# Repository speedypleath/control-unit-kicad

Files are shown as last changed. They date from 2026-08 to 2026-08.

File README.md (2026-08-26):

# Haptic Console — Control Unit (M6) KiCad Project

KiCad project for the Control Unit module of the Haptic Console v1.0. One schematic,
two PCBs: a compact manufactured board (SMD, routed, ready for fab) and a hand-wireable
perfboard build.

## Schematic

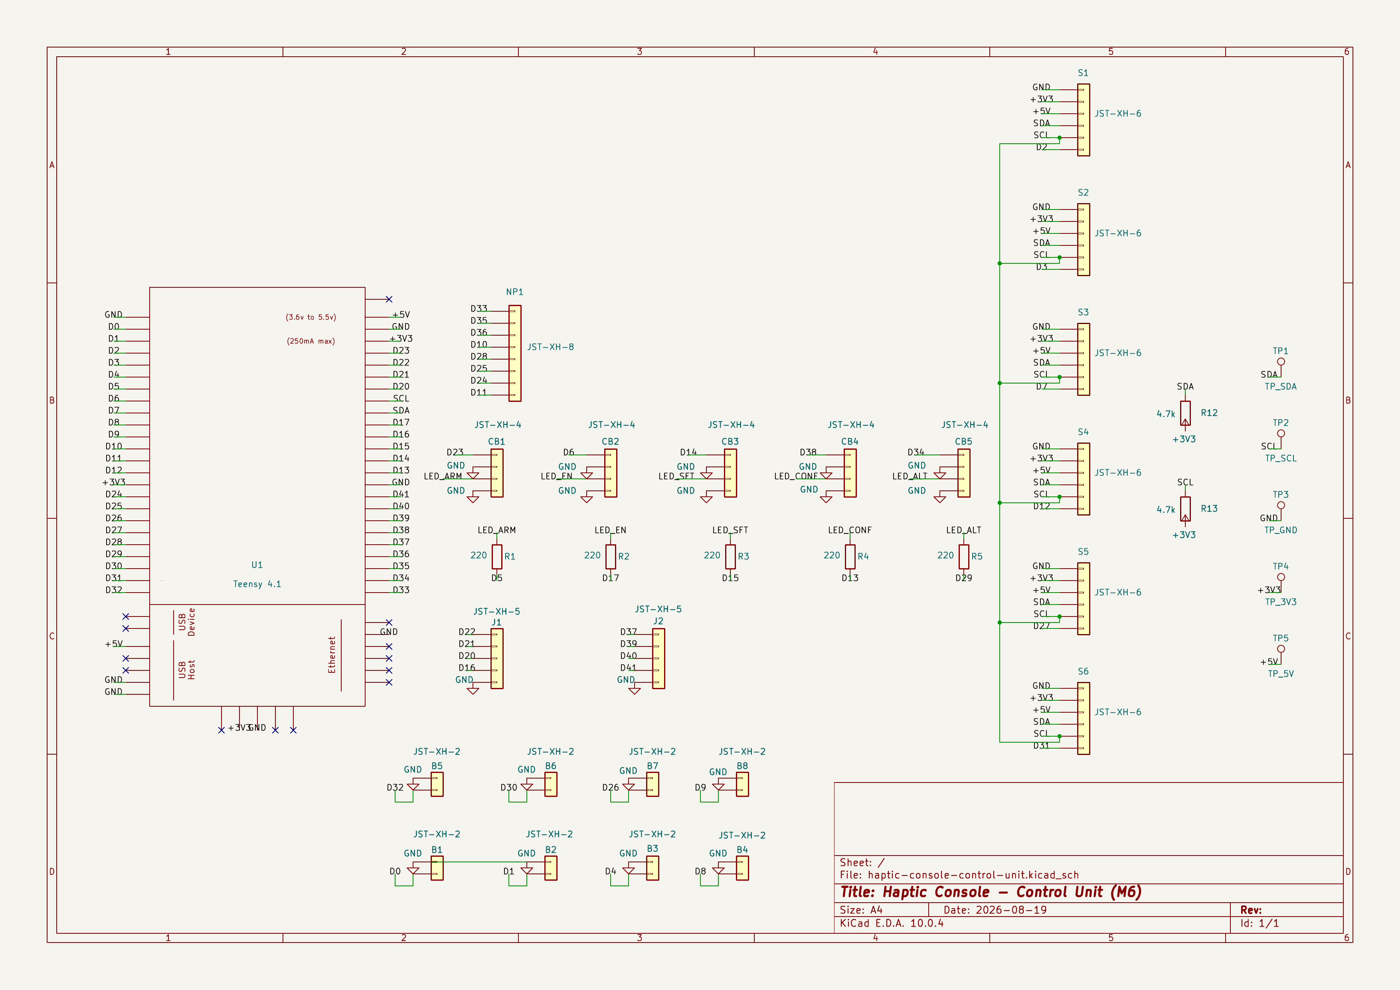
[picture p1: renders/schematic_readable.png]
Schematic


U1 Teensy 4.1, S1–S6 haptic driver connectors (6-pin JST-XH, [XH2.54 v1.1 standard](#connector-standard)),
B1–B8 tactile buttons, CB1–CB5 + R1–R5 LED/button conditioning, R12/R13 I²C pull-ups,
J1/J2 joystick headers, NP1 numpad matrix, TP1–TP5 test points (SDA/SCL/GND/+3V3/+5V,
tapped at the I²C pull-up network). ERC: 0 errors/0 warnings.

## Manufactured board

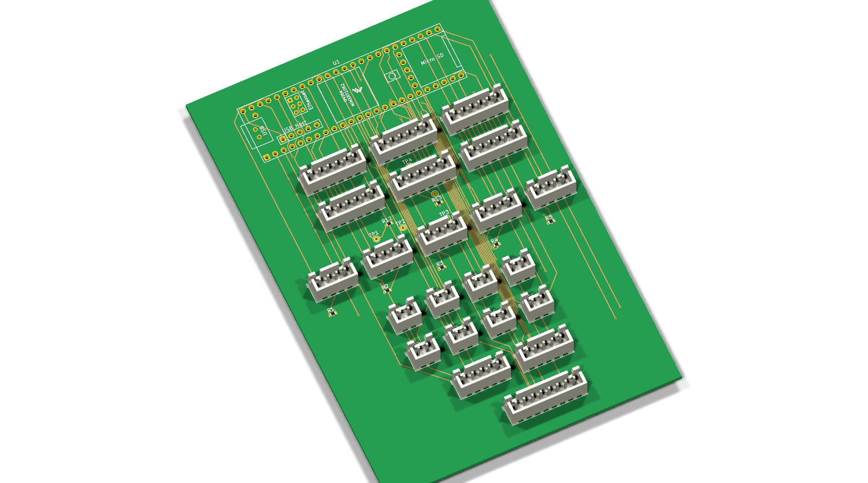
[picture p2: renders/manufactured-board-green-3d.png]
Manufactured board


Compact (88×131mm) layout, SMD 0603 resistors, fully autorouted (654 track segments,
35 vias, 0 unrouted nets), plus 5 THT test-point pads (TP1–TP5) for SDA/SCL/GND/+3V3/+5V
near R12/R13. DRC: 0 errors/0 warnings, 0 unconnected pads.

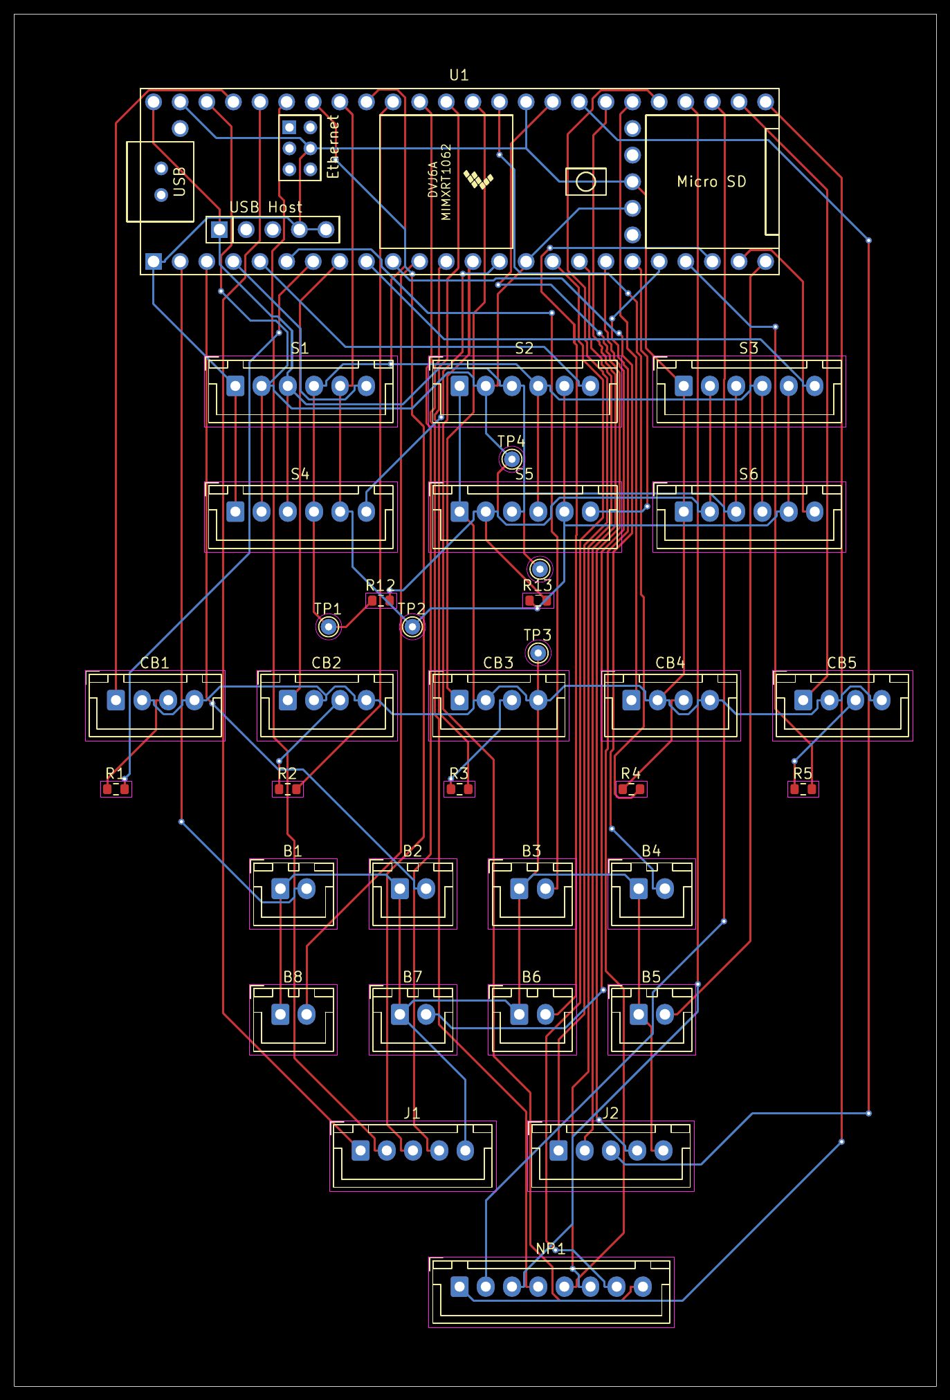
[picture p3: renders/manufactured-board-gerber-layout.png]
Gerber layout, top view


Gerbers + drill file: [`project/haptic-console-control-unit-gerbers.zip`](project/haptic-console-control-unit-gerbers.zip)
(Gerber X2 + Excellon drill, plain KiCad-default output — no fab-specific renaming).
View with [gerbv](https://gerbv.github.io/) or unzip and drag into your fab's order-check
tool (JLCPCB/PCBWay/OSH Park all accept the zip directly).

## Perfboard build

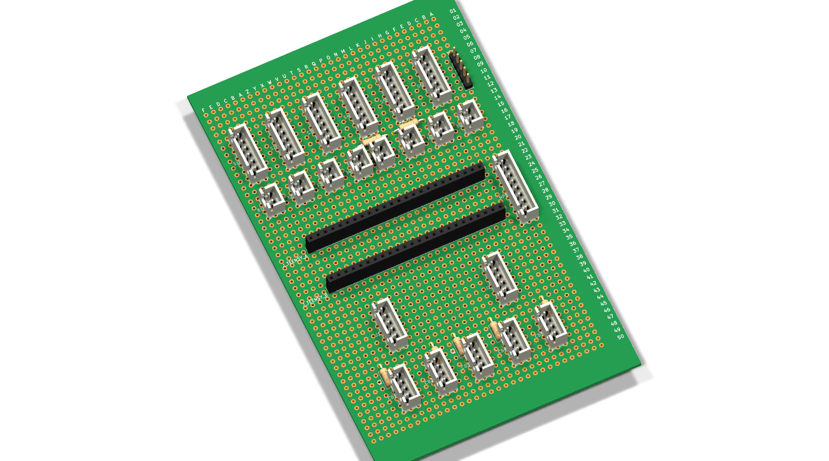
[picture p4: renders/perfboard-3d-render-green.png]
Perfboard


Hand-wireable 90×150mm 32×50-hole perfboard layout, same schematic/nets, laid out for
row/column GND+3V3+5V+SDA+SCL bus wiring, with 223 colour-coded back-side jumper wires
modelled in 3D (see [`docs/perfboard-wiring-regeneration.md`](docs/perfboard-wiring-regeneration.md)). TP1–TP5 are real male 2.54mm header pins
(not just pads) in the last column at the board's right edge, past S6 — clip a jumper
or scope hook straight on instead of back-probing a live JST connector. Full
per-connector wiring plan (every connection as a board grid reference, e.g.
`S1.1 → Q23`), live at
**[wiring-guide](https://speedypleath.github.io/control-unit-kicad/wiring-guide.html)**
(source: [`docs/wiring-guide.html`](docs/wiring-guide.html)). Print
[`renders/perfboard-placement-template-1to1.pdf`](renders/perfboard-placement-template-1to1.pdf)
at 100%/Actual Size for physical placement.

## GPIO assignment

Every connector signal is wired to whichever Teensy digital pin sits physically closest
to it, rather than to a contiguous block per function — 1356 mm of Manhattan run in total,
longest single wire 61 mm, 223 modelled jumper legs on the perfboard. The assignments are
therefore **not** sequential; the authoritative map is `scripts/pin_map.json`, rendered per
connector in the [wiring guide](docs/wiring-guide.html) and the
[panel wiring guide](docs/panel-wiring-guide.html). Firmware pin constants must follow
that map.

Eighteen conductors are **frozen** because they are already soldered on the built board and
are an input to the solver, not a result: B1–B8, both joysticks (J1/J2), and the LED4/LED5
lamp jumpers. Everything else — the six module IRQs, the five control-button switches, the
other three lamps and the eight numpad lines — is re-solved for proximity whenever the
layout moves. The Teensy plugs in **USB toward the `B23`/`B29` end**; if that is ever in
doubt, settle it by reading a hole off the physical board, never by checking whether the
resulting map looks sensible.

## Connector standard

S1–S6 haptic-module cables follow **XH2.54 6-pin — Haptic Console Connector Standard
v1.1**: pin 1 GND, pin 2 3.3V, pin 3 5V, pin 4 SDA, pin 5 SCL, pin 6 IRQ.

## Libraries

- `teensy.pretty` / `teensy.kicad_sym` — XenGi Teensy 4.1 footprint + symbol (not stock
  KiCad), vendored in `libraries/`.
- `Connector_JST`, `Resistor_THT`, `Resistor_SMD`, `Device`, `Connector_Generic`, `power`
  — stock KiCad 10 libraries.
- `digikey-kicad-library`, `SparkFun-KiCad-Libraries` — additional atomic parts.
- Project `fp-lib-table` / `sym-lib-table` wired for all of the above.

## Files

- `project/` — schematic, both boards, project files, lib tables, `gerbers/` +
  `*-gerbers.zip` (manufactured board fab output)
- `libraries/` — vendored XenGi `teensy.pretty`
- `renders/` — schematic + PCB renders
- `docs/` — wiring guide, build log, kicad-mcp lessons

## Sources

- Teensy 4.1 footprints: https://github.com/XenGi/teensy.pretty
- Digi-Key atomic parts: https://github.com/Digi-Key/digikey-kicad-library
- SparkFun: https://github.com/sparkfun/SparkFun-KiCad-Libraries
- KiCad stock footprints: https://gitlab.com/kicad/libraries/kicad-footprints

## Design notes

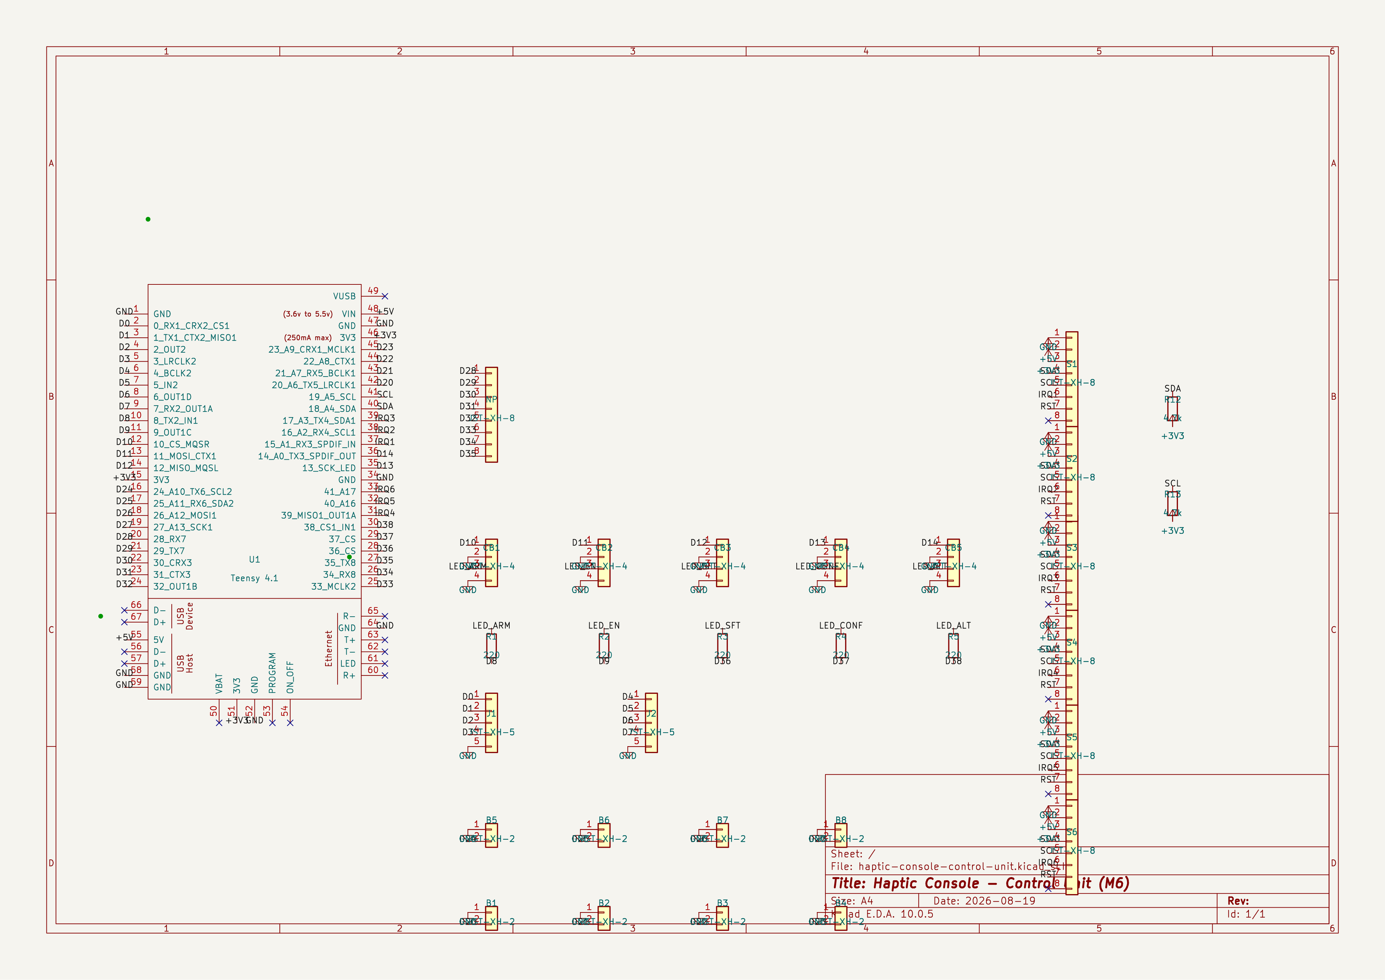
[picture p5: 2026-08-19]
renders/cu_schematic_full.png

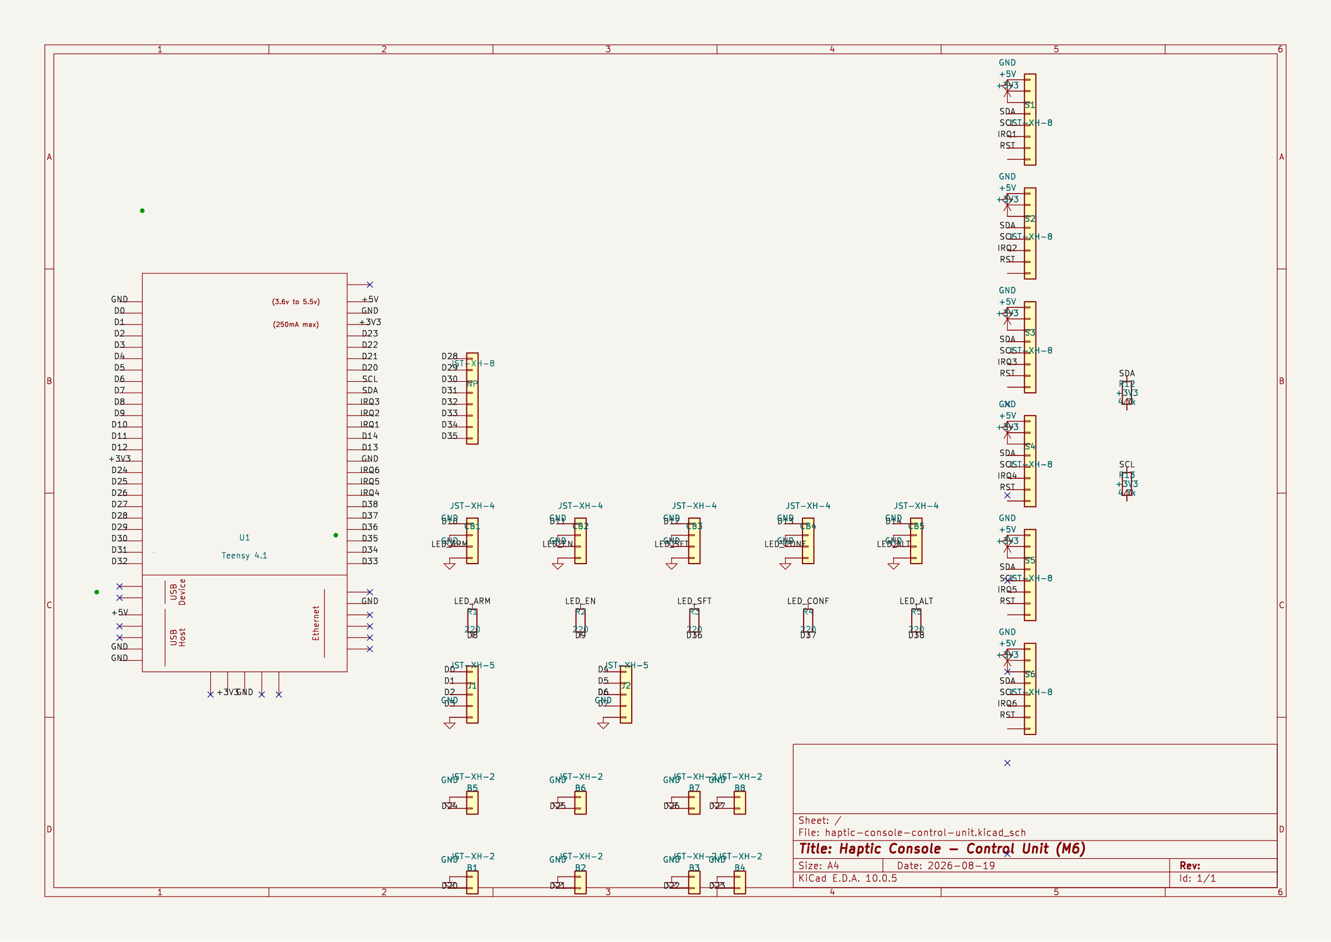
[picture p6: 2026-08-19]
renders/schematic-v2-cleanup.png

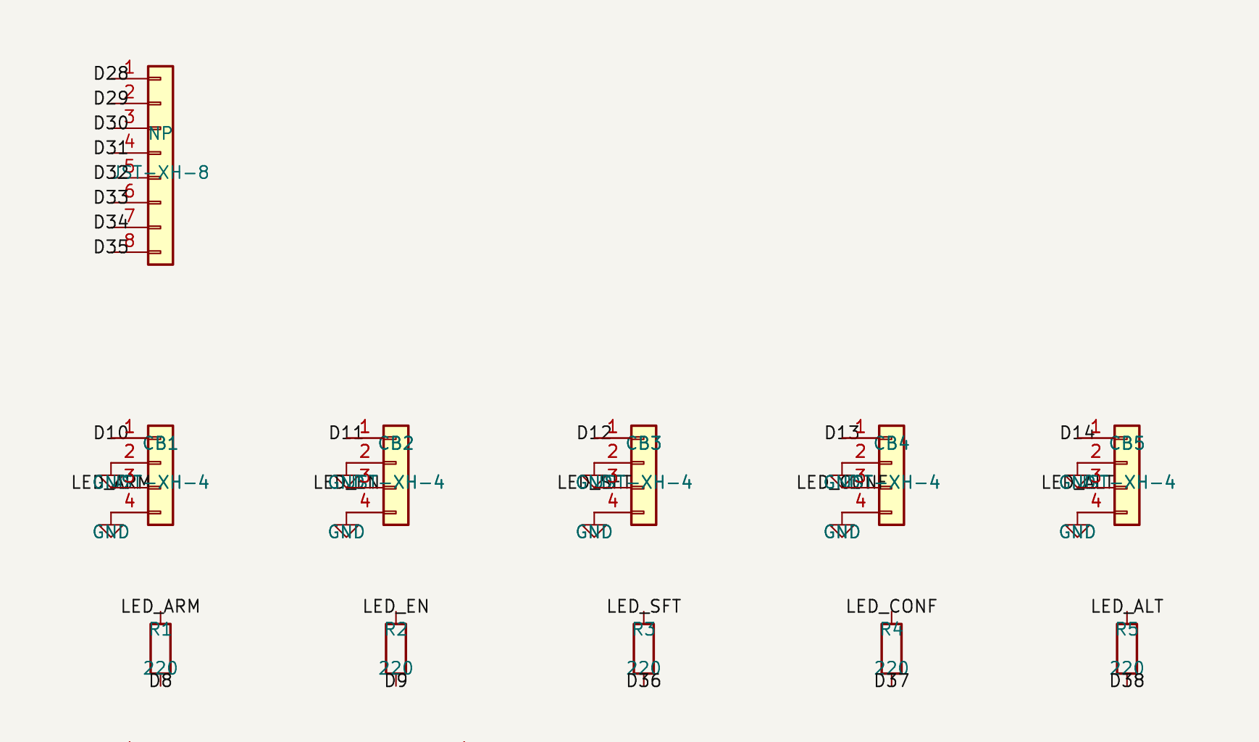
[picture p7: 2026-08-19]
renders/cu_detail_numpad.png

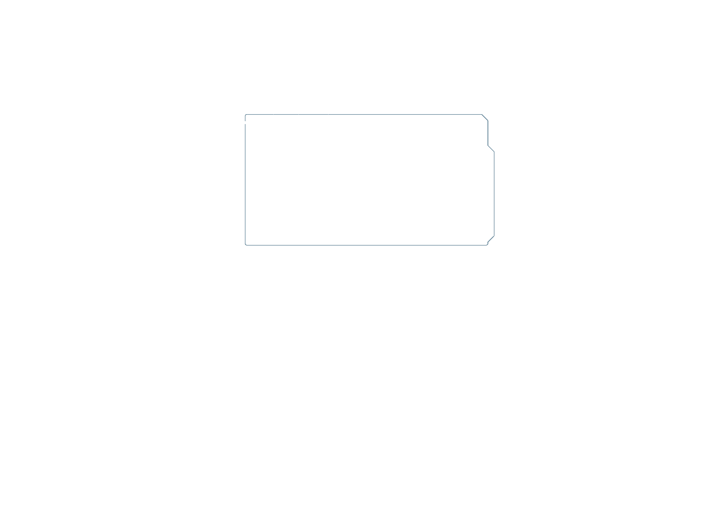
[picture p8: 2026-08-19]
renders/pcb_r2.png

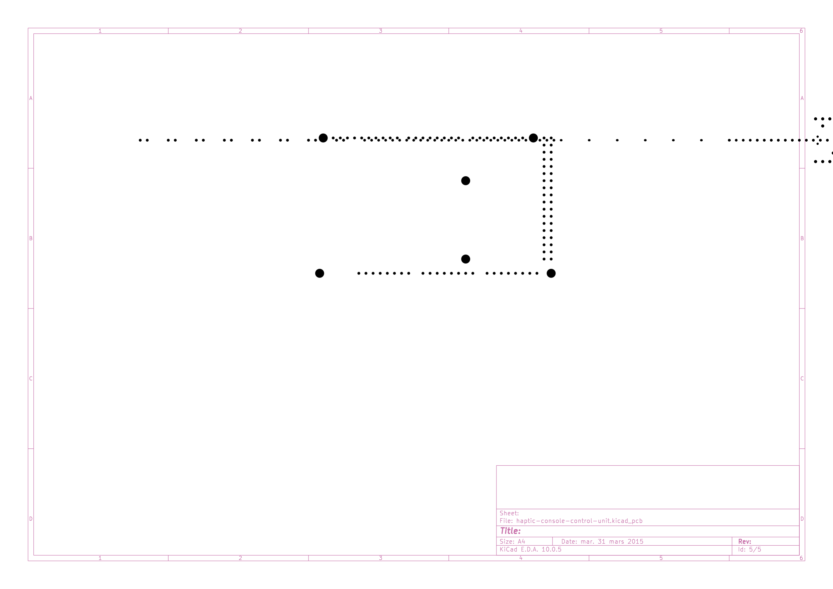
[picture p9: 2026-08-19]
renders/pcb_r2_B_Silkscreen.png

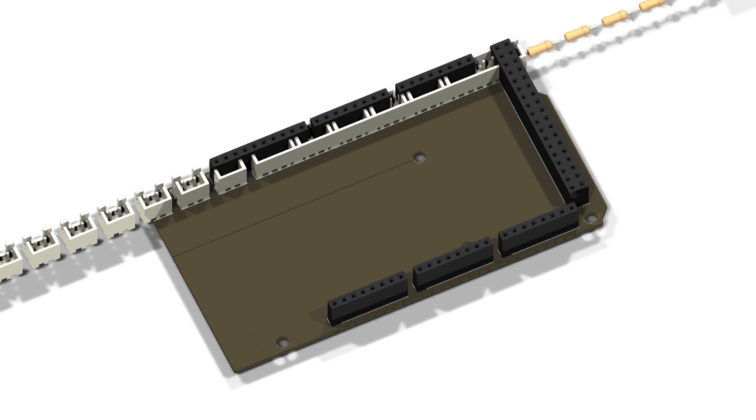
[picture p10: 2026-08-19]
renders/pcb_r2_3d_top.png

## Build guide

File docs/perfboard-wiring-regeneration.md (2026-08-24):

# Regenerating the perfboard's jumper wiring

The perfboard's back-side wiring is a set of **decorative** footprints from
`~/KiCad/jumper-wires-kicad` — no pads, no nets, no copper. DRC never sees them
(478 violations before and after, byte-identical violation set). Their whole job
is to be *readable*, so the quality bar is visual: no two wires may merge.

Everything needed to regenerate them lives in `scripts/`.

## Why wires merged, and the two different fixes

| Failure | Fix |
| --- | --- |
| **Collinear overlap** — two wires on the same row/column with overlapping spans | Cannot be hidden by height. Prevented during routing by a span registry. |
| **Mid-span crossing** — a horizontal wire and a vertical wire meet at a point | Unavoidable on a board this dense, and fine if the two sit at different heights. Fixed after routing by graph-colouring the nets and using the colour as the z tier. |

The 163-segment set that preceded this pipeline had **55 same-tier collinear
overlaps**. The current 203-segment set has **zero**.

## Pipeline

```bash
cd scripts
python3 gen_pin_map.py                     # -> pin_map.json  (GPIO <- nearest Teensy pin)
python3 gen_taps.py                        # -> taps_clean.json + net_meta.json
python3 gen_segments_v3.py                 # -> segments_v3.json
python3 verify_v3.py segments_v3.json      # connectivity / tap coverage / bounds
python3 analyze_conflicts.py segments_v3.json   # overlap + crossing census
```

Then apply, always to a **copy of the board first**:

```bash
KPY=/Applications/KiCad/KiCad.app/Contents/Frameworks/Python.framework/Versions/3.9/bin/python3
$KPY scripts/remove_wires.py <board.kicad_pcb>          # 239 -> 36 footprints
$KPY ~/KiCad/jumper-wires-kicad/scripts/place_wire.py \
     <board.kicad_pcb> scripts/segments_v3.json          # 36 -> 239
kicad-cli pcb drc --severity-all --format report <board.kicad_pcb> -o /tmp/drc.rpt
```

The DRC violation *set* (not just the count) must come back identical to the
pre-wiring baseline. `place_wire.py`'s success message is not evidence of
anything on this file — check `grep -c '(footprint'` yourself, per the standing
rule in `CLAUDE.md`.

Regenerating the board also re-creates the stray
`haptic-console-control-unit-perfboard.kicad_pro` / `.kicad_prl`. Delete them.

## Routing, in brief

- **Buses** (`GND`, `+3V3`, `+5V`, `SCL`, `SDA`) route as a Manhattan MST over
  their taps, so same-row taps chain straight along a connector's pin row.
- **Everything else** routes by A* over the hole grid, one straight leg per move,
  with a turn penalty (`TURN`, fewer jogs) and a crossing penalty
  (`CROSS_PENALTY`, fewer conflict-graph edges → fewer tiers → a flatter stack).
  The 25/40 pair currently in the file was picked by sweeping both.

Three constraints in the generator each exist because violating them produced a
specific, real bug — don't "simplify" them away:

- **Legs may run along pad rows/columns**, as long as they don't pass strictly
  *through* a pad. Only 4 of ~36 columns and 14 of ~54 rows are pad-free, and
  they all hug the board edge, so restricting turns to pad-free lanes left 19 of
  37 signal nets unroutable.
- **Routable lines include each pad's exact coordinate**, not just the nominal
  2.54mm grid. JST pad rows sit at y=15.44 where the grid says 15.24; grid-only
  routing forced a 0.2mm hop off every such pad, which the stub filter then
  deleted, silently disconnecting nets from their own pins.
- **Merging preserves the exact line coordinate.** Runs are *grouped* by a
  0.1mm-quantised key, but the merged segment keeps the real coordinate —
  rounding a run at y=17.94 to 17.90 slides the wire off its pad.

`verify_v3.py` is what catches all three: it checks that every one of the 157
taps lies on a wire and that each net's segments form one connected component.
A wire set can be perfectly overlap-free and still be an open circuit.

## Tier heights

`place_wire.py` lifts a wire by `z_tier * 1.0mm` and accepts fractional tiers.
Colouring needs 6 tiers here; at whole-number steps the top wire would float 5mm
off the board. `assign_tiers()` scales the step so the whole stack fits under
`MAX_LIFT = 2.0mm` while keeping the strict per-tier ordering that makes a
crossing render as over/under.

## Ground truth

`taps_clean.json` (157 taps, 50 nets) and `net_meta.json` (per-net colour, label,
and endpoint `REF.PIN` pair) are generated by **`gen_taps.py`** from
`pin_map.json` — the GPIO assignment produced by `gen_pin_map.py`, which gives
every connector signal the Teensy pin physically nearest to it. That map is the
single source of truth shared by the schematic, the manufactured board's nets,
and this wiring; changing a pin means re-running `gen_pin_map.py` → `gen_taps.py`
→ `gen_segments_v3.py`, not editing segment JSON by hand.

`reconstruct_segments.py` recovers a segment list from wire footprints already on
a board (position, rotation, `m_Scale.x`, `m_Offset.z`, colour, label). It was how
the first clean tap set was salvaged and is still useful for inspecting a board
whose JSON has been lost — but it is **no longer the ground truth**. Deriving taps
from wire *geometry* is what produced the original bad `taps.json`, which counted
elbow corner points as taps; several of those happen to sit on an unrelated
component's pad, inventing connections that don't exist.

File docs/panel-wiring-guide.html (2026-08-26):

Haptic Console · Control Unit · Panel Loom

# Panel Loom Wiring Guide

The other half of the build: what goes into each JST connector on the control-unit perfboard. The board wiring guide stops at the connector pads — this one starts there and runs out to the buttons, joysticks, numpad and sensor modules on the panel.

Power (+5V / +3V3)

Ground / switch common

I²C bus (SCL / SDA / IRQ)

Signal (GPIO in or LED out)

## Before you crimp anything

Four conventions hold across every connector on this panel. Get these right and each individual cable below is mechanical.

Every switch is wired common-to-GND. No switch on this panel gets power. One terminal goes to the connector's GND pin, the other to its signal pin. The firmware holds every input with an internal pull-up, so an open switch reads HIGH and a closed one reads LOW. Momentary NO microswitches are non-polar — which of the two terminals you use for which does not matter.

Every LED is active HIGH. Anode to the connector's LED pin, cathode to its GND pin. The series resistors (R1–R5, 220 Ω) are already on the board, so the LED you fit must be a bare LED — not a pre-wired 5V or 12V illuminated button assembly with its own internal resistor, which will not light from 3.3 V through another 220 Ω.

Pin 1 is the pin listed first in the board guide's table for that connector. Don't rely on a housing marking to tell you which end is which — go back to the board wiring guide, read the grid ref for pin 1, and find that hole. Every table below numbers the board connector's pins, not the device's.

Pin numbers have moved several times; this 2026-08-26 map supersedes every earlier one. Every connector signal sits on whichever Teensy pin is physically closest to it on the board, so the assignments are not contiguous blocks (B1–B8 are not D20–D27, the numpad is not D28–D35). Cables and connector pinouts are unchanged — only the firmware pin constants need updating. One constraint overrides proximity: the seventeen already-soldered conductors are frozen — B1–B8 (D0 D1 D4 D8 / D32 D30 D26 D9), both joysticks, J1 (D22 D21 D20 D16) and J2 (D37 D39 D40 D41), and CB5's lamp (D29) — so only the other control-button lines, the numpad and the module IRQs were re-optimised. This pass also settled the Teensy's orientation against the physical board: it plugs in USB toward the B23/B29 end, and each socket carries its Teensy pin row in that row's own order, neither reversed — board row 23 is GND D0…D12 +3V3 D24…D32, board row 29 is +5V GND +3V3 D23…D13 GND D41…D33. Two earlier revisions had this wrong in different ways, which is why almost every unfrozen signal changed pin again. Both joystick sub-arrays in the firmware's kJoystickPins are correct as written — an intermediate revision of this page swapped them, which was a workaround for the bad orientation, not a real crossing. An eighteenth conductor joined the frozen set once R4's LED jumper was re-landed in O29: CB4's lamp is fixed on D13. The schematic, both PCBs and the gerbers are all resynced to this map as of 2026-08-26 — they and this page are generated from the same scripts/pin_map.json.

Cable stock: JST-XH 2.54 mm housings, 24–26 AWG stranded. Stranded, not solid — these runs flex every time the panel comes off.

## B1–B8 — action buttons

Eight plain momentary buttons, two conductors each. B1–B4 are the left cluster, B5–B8 the right. They send MIDI notes 46–53 on channel 16, in that order.

## CB1–CB5 — lit control buttons

Four conductors each: a switch and an LED sharing one housing, with a separate ground for each so a shorted lamp can't pull the switch line down with it. Notes 54–58 on channel 16. Each press also toggles that button's own lamp, so the panel shows mode state without the host having to drive it.

CB4's lamp sits on D13, the Teensy's onboard-LED pin. That is safe only because it is a driven output — the onboard LED and its resistor hang off D13 and would fight a pull-up input, so no input signal is allowed on that pin. The visible side effect is that the onboard LED lights whenever the CONF lamp does. Never move a switch (pull-up input) onto D13.

## J1 / J2 — joysticks

Four-microswitch digital sticks, not analog: a common terminal and one normally-open switch per gate direction. J1 is the left stick, J2 the right.

The stick's own lead plugs in end-for-end. A typical 5-way arcade stick numbers its lead 1 common, 2 down, 3 up, 4 right, 5 left — common on pin 1. The board puts GND on pin 5. Crimping the lead reversed (its pin 1 onto board pin 5, its pin 2 onto board pin 4, and so on down) puts common on ground and lands left/right/up/down exactly on board pins 1–4, with no wires crossed inside the housing.

That is the loom this firmware assumes. If your stick numbers its lead differently, either re-crimp to match the table above or reorder kJoystickPins in lib/TeensyPanelCore/src/TeensyPanelCore.h — do not cross wires inside the housing, where nobody will find them later. Either way, push the stick in all four directions against the serial monitor before you close the panel.

## NP1 — numpad

A 4×4 matrix on eight conductors and no ground at all. The firmware drives one row LOW at a time and reads the four columns with pull-ups, so the matrix supplies its own reference — there is nothing to connect to GND.

From a 10-way membrane tail, this is a straight-through crimp. That keypad's own tail runs 1 unused, 2–5 columns 0–3, 6–9 rows 0–3, 10 unused. Tail pin 2 goes to NP1 pin 1, tail pin 3 to NP1 pin 2, and so on to tail pin 9 on NP1 pin 8. Both unused ends are left off the housing.

No numpad conductor is on D13 any more — that pin now drives CB4's lamp. It stays reserved for driven outputs either way: the onboard LED and its series resistor hang off D13 and would fight a pull-up, so a column line must never be moved onto it.

Ring it out in resistance mode, not continuity mode. A membrane keypad's closed contact measures somewhere between 500 Ω and 10 kΩ — real conduction, but far too resistive to trip most multimeters' continuity beeper. A silent meter here means "membrane", not "open circuit".

## S1–S6 — sensor modules

Six identical slots for Pico-based I²C sensor modules, on the six-pin Haptic Console Connector Standard v1.1. Every slot is wired the same, so a module can move between slots; only the IRQ line is per-slot.

Power the Pico from VSYS, never from 3V3. Connector pin 3 (+5V) goes to the Pico's VSYS; its own regulator makes the 3.3 V. Connector pin 2 (+3V3) is a reference rail only — leave it off the Pico entirely rather than back-feeding the Pico's regulator from both sides.

The bus pull-ups are already on the board. R12 and R13 (4.7 kΩ) pull SDA and SCL to +3V3 at the master end. Don't add another pair on a module, and never pull either line to 5 V — the Pico's GPIO is not 5 V tolerant.

v1.1 drops RESET and ID/ADDR from the original eight-pin standard. Nothing on this board can hard-reset a wedged module, and the Pico's ID/ADDR input (GP26) is left floating — so the idAdc field the Teensy prints in each packet is an unconnected-input reading, not a board identity. Read it as diagnostic noise until a board carries the resistor ladder.

## What the firmware does with each one

Every pin below is a real net on the built board, taken from the control-unit schematic netlist. The firmware's copy of this table lives in lib/TeensyPanelCore/src/TeensyPanelCore.h, and a host-side test asserts the two stay in step.

Connector | Teensy pin | Role | MIDI

## Check before first power-on

The +5V rail is the Teensy's VIN pin. On USB power alone the whole console — Teensy, six Pico modules, every lamp — shares one 500 mA budget, which six modules will not fit inside. If you feed an external 5 V supply into VIN instead, cut the VUSB–VIN pads on the underside of the Teensy first; leaving them joined ties your bench supply to the host computer's USB rail.

Nothing on this panel should be closed at rest. Ring every switch out open before the connector goes on. The firmware's boot self-test prints all panel inputs open when it agrees with you, and names each offender when it doesn't.

## Bring-up order

Plug in one family at a time. A panel that comes up all at once gives you no way to tell which loom is wrong.

1. Power the Teensy over USB with every panel connector unplugged. Open the serial monitor at 115200 baud. The self-test should report all panel inputs open.
2. Plug in B1–B8. Reset, confirm the self-test is still clean, then press each button and watch for B1 pressed … B8 released in order. A button that prints the wrong number is a swapped pair, not a firmware bug.
3. Plug in CB1–CB5. Each press should print its legend (ARM, EN, SFT, CONF, ALT) and toggle that button's lamp.
4. Plug in J1 and J2. Push each stick to all four gates and confirm the CC values move the way the table says: left 0, centre 64, right 127.
5. Plug in NP1. Every digit key should print and send its note; A B C D * # print but have no note mapping yet. Watch row 3 in particular — see the pin 13 note above.
6. Plug in one sensor module, on S1. Press s to rescan the bus, then i for the per-slot IRQ report — the slot you used should be the one counting up. Add the rest one slot at a time.

Serial commands: d toggles debug output, i prints the IRQ report, s rescans the I²C bus.

Companion to the control-unit Wiring Guide, which covers the perfboard side of the same connectors. Every pin assignment here was taken from the schematic netlist of haptic-console-control-unit.kicad_sch and cross-checked against the connector placement in haptic-console-control-unit-perfboard.kicad_pcb. Firmware pin map: lib/TeensyPanelCore/src/TeensyPanelCore.h in the haptic-console-firmware repo.

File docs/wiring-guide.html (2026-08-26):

Haptic Console · Control Unit · Perfboard Build

# Wiring Guide

Every connection, given as the actual perfboard hole (column letter + row number, matching the printed grid on your board) — not an abstract header-pin number. Read a grid ref, find that hole, solder. Click any grid ref to light up every other mention of that same hole.

0/107 reset auto

Power (+5V / +3V3) — red kit wire Ground — blue kit wire I²C bus (SCL / SDA / IRQ) — yellow kit wire Signal (per-pin GPIO) — white / orange / green kit wire

## Using the jumper wire kit

You're wiring this with a pre-formed solid-core jumper kit (the boxed assortment of red/yellow/white/orange/green/blue wires, fixed pre-cut lengths, ends bent square) — the standard kit sold for solderless breadboards. That matters for a few reasons specific to this board:

These wires are made for solderless boards — this perfboard isn't one. The bent tip is shaped to grip a breadboard's spring clip, not to make a reliable joint on its own. It will friction-fit into a perfboard hole and feel "connected," but it isn't electrically sound until soldered. Treat every insertion as a dry-fit, not a finished connection:

1. Push the wire's tip through the two holes the guide calls out (component-side/top of the board), and check the fit against the grid ref before committing.
2. Flip the board to the copper/solder side and solder both tips to their pads. A perfboard pad is just a ring of copper around the hole — feed a little solder onto the joint so it wets the ring, not just the wire.
3. Clip the excess tip flush once the joint has cooled.

The kit's lengths are fixed — the "rail" runs below are not. A shared bus row (GND/+3V3/+5V/SCL/SDA, see Shared bus rails below) usually spans more holes than any single wire in the kit. Two options, both fine:

- Pick the longest wire that reaches and let it bow slightly between holes — solid core holds its shape, it won't spring back.
- Daisy-chain shorter wires hole-to-hole along the row: at every intermediate hole, both the incoming and outgoing wire tips land in the same hole and both get soldered there together with the pad. Don't skip soldering an intermediate joint just because the wire "looks continuous" — each hole is a separate solder joint, there's no copper trace linking adjacent holes on bare perfboard.

The solder checklist already lists each rail hop separately, with its length in millimetres, so you can match a hop to a wire in the box before cutting anything.

Colour convention (matches the legend above, the kit's actual colours, and the 3D-modelled wires on the board): red for every +5V/+3V3 connection, blue for every GND connection (the kit has no black — blue is the closest "stay off the power colours" choice and reads unambiguously once you commit to it), yellow for the SCL/SDA/IRQ bus, and white/orange/green for the remaining signal wires. Each signal net gets one fixed colour, so the same wire is the same colour everywhere it appears — on this page, on the diagram, and in the 3D render. The checklist's colour column is the authority.

Test before you solder the far end. The small compartment of premade spade/hook-tipped leads in the kit box is handy for exactly this: clip one onto a wire you've already soldered at one end and touch the other lead to the destination pad with a multimeter in continuity mode, confirming against the grid ref, before soldering the second end permanently.

## Back-side wiring diagram

The board seen from the solder side (mirrored), with every jumper drawn where it actually runs on the finished board. Wires that cross are drawn in physical over/under order.

power (+5V / +3V3) ground I²C bus (SCL / SDA / IRQ) signal — white signal — orange signal — green

The Teensy header sockets aren't outlined (48 near-parallel verticals would crowd the top of the diagram) — every net still ends at its correct header column. Signal colours are per net, not per connector group, so two adjacent wires can share a colour; cross-check the net name in the tables below.

## Teensy header pinout

The two 24-pin sockets the Teensy drops into, drawn left to right as they sit on the board. Each cell shows the socket pin number, the perfboard hole under it, the Teensy net, and what this build wires to it. Greyed cells are unused — free for later expansion.

### Header A — board row 23 (upper socket)

pin 1 at the left edge — the Teensy's USB end

1B23GNDrail

2A23D0B1.2

3Z23D1B2.2

4Y23D2S1.6

5X23D3S2.6

6W23D4B3.2

7V23D5R1.2

8U23D6CB2.1

9T23D7S3.6

10S23D8B4.2

11R23D9B8.2

12Q23D10NP1.4

13P23D11NP1.8

14O23D12S4.6

15N23+3V3rail

16M23D24NP1.7

17L23D25NP1.6

18K23D26B7.2

19J23D27S5.6

20I23D28NP1.5

21H23D29R5.2

22G23D30B6.2

23F23D31S6.6

24E23D32B5.2

### Header B — board row 29 (lower socket)

pin 1 at the left edge — the Teensy's USB end

1B29+5Vrail

2A29GNDrail

3Z29+3V3rail

4Y29D23CB1.1

5X29D22J1.1

6W29D21J1.2

7V29D20J1.3

8U29D19—

9T29D18—

10S29D17R2.2

11R29D16J1.4

12Q29D15R3.2

13P29D14CB3.1

14O29D13R4.2

15N29GNDrail

16M29D41J2.4

17L29D40J2.3

18K29D39J2.2

19J29D38CB4.1

20I29D37J2.1

21H29D36NP1.3

22G29D35NP1.2

23F29D34CB5.1

24E29D33NP1.1

## Shared bus rails

Five nets touch many holes each. Run each as one continuous chain past every hole listed, in the order listed (that's board order, top to bottom), rather than home-running each connector back to the header separately.

GND · 30 taps · blue wire

D11 Y11 T11 O11 J11 E11 A11 D16 Z16 V16 R16 O16 K16 G16 C16 B23 A29 N29 X35 I35 Z44 U44 P44 K44 F44 Z46 U46 P46 K46 F46

+3V3 · 11 taps · red wire

A10 D10 Y10 T10 O10 J10 E10 M13 H13 N23 Z29

+5V · 8 taps · red wire

A09 D09 Y09 T09 O09 J09 E09 B29

SDA · 9 taps · yellow wire

A08 D08 Y08 T08 O08 J08 E08 Q13 T29

SCL · 9 taps · yellow wire

A07 D07 Y07 T07 O07 J07 E07 L13 U29

## Test points

Five male 2.54mm header pins in the last column past S6 (column A — the letter sequence wraps back to A at the board's right edge), tapping the same rails S1–S6 share. Clip a jumper or scope hook straight onto a pin instead of back-probing a live JST connector.

TP2 · SCL

A07

TP1 · SDA

A08

TP5 · +5V

A09

TP4 · +3V3

A10

TP3 · GND

A11

## Connectors

## S1–S6 — haptic drivers (I²C)

Rotated vertical, one per column, centred on the board. GND/+3V3/+5V/SDA/SCL all fall on the same row across all six — a horizontal bus wire along that row reaches every connector. Only pin 6 (IRQ) is unique per connector.

S1JST-XH-6 · col D

1 | D11 | GND | GND rail
2 | D10 | +3V3 | +3V3 rail
3 | D09 | +5V | +5V rail
4 | D08 | SDA | SDA rail
5 | D07 | SCL | SCL rail
6 | D06 | IRQ1 | D2 → Y23

S2JST-XH-6 · col Y

1 | Y11 | GND | GND rail
2 | Y10 | +3V3 | +3V3 rail
3 | Y09 | +5V | +5V rail
4 | Y08 | SDA | SDA rail
5 | Y07 | SCL | SCL rail
6 | Y06 | IRQ2 | D3 → X23

S3JST-XH-6 · col T

1 | T11 | GND | GND rail
2 | T10 | +3V3 | +3V3 rail
3 | T09 | +5V | +5V rail
4 | T08 | SDA | SDA rail
5 | T07 | SCL | SCL rail
6 | T06 | IRQ3 | D7 → T23

S4JST-XH-6 · col O

1 | O11 | GND | GND rail
2 | O10 | +3V3 | +3V3 rail
3 | O09 | +5V | +5V rail
4 | O08 | SDA | SDA rail
5 | O07 | SCL | SCL rail
6 | O06 | IRQ4 | D12 → O23

S5JST-XH-6 · col J

1 | J11 | GND | GND rail
2 | J10 | +3V3 | +3V3 rail
3 | J09 | +5V | +5V rail
4 | J08 | SDA | SDA rail
5 | J07 | SCL | SCL rail
6 | J06 | IRQ5 | D27 → J23

S6JST-XH-6 · col E

1 | E11 | GND | GND rail
2 | E10 | +3V3 | +3V3 rail
3 | E09 | +5V | +5V rail
4 | E08 | SDA | SDA rail
5 | E07 | SCL | SCL rail
6 | E06 | IRQ6 | D31 → F23

## R12 / R13 — I²C pull-ups

Sit just below the S-zone, tapping the SDA/SCL/+3V3 rails directly. 4.7 kΩ each.

R124.7 kΩ · row 13

1 | Q13 | SDA | SDA rail
2 | M13 | +3V3 | +3V3 rail

R134.7 kΩ · row 13

1 | L13 | SCL | SCL rail
2 | H13 | +3V3 | +3V3 rail

## B1–B8 — diamond buttons (mirrored)

B1–B4 (left cluster) mirror B5–B8 (right cluster) on the same row band, so left to right the refs read B1 B2 B3 B4 B8 B7 B6 B5 — the cards below are in that physical order, not numeric order. All eight pin-1 (GND) holes share one row: a single wire down that row grounds all eight.

B1JST-XH-2 · col D

1 | D16 | GND | GND rail
2 | D15 | B1 | D0 → A23

B2JST-XH-2 · col Z

1 | Z16 | GND | GND rail
2 | Z15 | B2 | D1 → Z23

B3JST-XH-2 · col V

1 | V16 | GND | GND rail
2 | V15 | B3 | D4 → W23

B4JST-XH-2 · col R

1 | R16 | GND | GND rail
2 | R15 | B4 | D8 → S23

B8JST-XH-2 · col O

1 | O16 | GND | GND rail
2 | O15 | B8 | D9 → R23

B7JST-XH-2 · col K

1 | K16 | GND | GND rail
2 | K15 | B7 | D26 → K23

B6JST-XH-2 · col G

1 | G16 | GND | GND rail
2 | G15 | B6 | D30 → G23

B5JST-XH-2 · col C

1 | C16 | GND | GND rail
2 | C15 | B5 | D32 → E23

## J1 / J2 — joysticks (mirrored)

J1 (left stick) mirrors J2 (right stick); pin 5 (GND) on both lands on the same row.

J1JST-XH-5 · col X

1 | X39 | J1.1 | D22 → X29
2 | X38 | J1.2 | D21 → W29
3 | X37 | J1.3 | D20 → V29
4 | X36 | J1.4 | D16 → R29
5 | X35 | GND | GND rail

J2JST-XH-5 · col I

1 | I39 | J2.1 | D37 → I29
2 | I38 | J2.2 | D39 → K29
3 | I37 | J2.3 | D40 → L29
4 | I36 | J2.4 | D41 → M29
5 | I35 | GND | GND rail

## CB1–CB5 — LED buttons (near-symmetric)

CB3 sits on the centre column; CB2/CB4 and CB1/CB5 mirror around it. Pin 3 is the LED anode and does not go to the Teensy — it goes to that connector's series resistor in the next column across, and the resistor's far end carries the GPIO. Both GND pins (2 and 4) sit on their own rows across all five. CB4's lamp is on D13, the Teensy's onboard-LED pin — safe only because a lamp is a driven output; never move a switch (pulled-up input) onto that pin.

CB1JST-XH-4 · col Z

1 | Z47 | CB1 | D23 → Y29
2 | Z46 | GND | GND rail
3 | Z45 | LED_ARM | → R1.1 A45
4 | Z44 | GND | GND rail

CB2JST-XH-4 · col U

1 | U47 | CB2 | D6 → U23
2 | U46 | GND | GND rail
3 | U45 | LED_EN | → R2.1 T45
4 | U44 | GND | GND rail

CB3JST-XH-4 · col P

1 | P47 | CB3 | D14 → P29
2 | P46 | GND | GND rail
3 | P45 | LED_SFT | → R3.1 Q45
4 | P44 | GND | GND rail

CB4JST-XH-4 · col K

1 | K47 | CB4 | D38 → J29
2 | K46 | GND | GND rail
3 | K45 | LED_CONF | → R4.1 L45
4 | K44 | GND | GND rail

CB5JST-XH-4 · col F

1 | F47 | CB5 | D34 → F29
2 | F46 | GND | GND rail
3 | F45 | LED_ALT | → R5.1 E45
4 | F44 | GND | GND rail

## R1–R5 — LED series resistors

Standing upright in the column beside their own connector, pin 1 on row 45 — the same row as that connector's pin 3 — and pin 2 four holes up on row 41, pointing at the Teensy header. R2 and R5 sit one column to the right of their CB; R1, R3 and R4 one column to the left. That puts every LED-cathode jumper at a single 2.6 mm hole-to-hole hop (CB1.3 Z45 → R1.1 A45 and so on) instead of the 25–50 mm runs the old row-48 placement needed.

R1220 Ω · col A

1 | A45 | LED_ARM | ← CB1.3 Z45
2 | A41 | LED1 | D5 → V23

R2220 Ω · col T

1 | T45 | LED_EN | ← CB2.3 U45
2 | T41 | LED2 | D17 → S29

R3220 Ω · col Q

1 | Q45 | LED_SFT | ← CB3.3 P45
2 | Q41 | LED3 | D15 → Q29

R4220 Ω · col L

1 | L45 | LED_CONF | ← CB4.3 K45
2 | L41 | LED4 | D13 → O29

R5220 Ω · col E

1 | E45 | LED_ALT | ← CB5.3 F45
2 | E41 | LED5 | D29 → H23

## NP1 — numpad

Pushed to the board's right edge to clear the Teensy header rows it shares rows with. Watch the labels here: the board's 32-column letter sequence reuses each letter at both ends, so NP1's holes can compute to the same letter+row as a header hole at the opposite edge. Use the left/right position, not the label alone. No numpad conductor is on D13 any more — that pin drives CB4's lamp. It stays reserved for driven outputs either way: the Teensy's onboard LED hangs off D13 and would fight a pull-up, so a column line must never be moved onto it.

NP1JST-XH-8 · col B

1 | B30 | NP1.1 | D33 → E29
2 | B29 | NP1.2 | D35 → G29
3 | B28 | NP1.3 | D36 → H29
4 | B27 | NP1.4 | D10 → Q23
5 | B26 | NP1.5 | D28 → I23
6 | B25 | NP1.6 | D25 → L23
7 | B24 | NP1.7 | D24 → M23
8 | B23 | NP1.8 | D11 → P23

## Solder checklist

Every wire on the board, once. 107 connections, 3006 mm of wire in total; the longest single run is 109 mm (+5V, S6.3 → J_TEENSY_B.1). Lengths are hole-to-hole Manhattan distance — the routed wire follows the grid, so that is its length, but add a few millimetres for the bend at each tip. Ticks are saved in this browser only.

all power ground I²C / IRQ signal

| colour | net | signal | from | to | mm
| blue | GND | | D11 S1.1 | Y11 S2.1 | 12.7
| blue | GND | | Y11 S2.1 | T11 S3.1 | 12.7
| blue | GND | | T11 S3.1 | O11 S4.1 | 12.7
| blue | GND | | O11 S4.1 | J11 S5.1 | 12.7
| blue | GND | | J11 S5.1 | E11 S6.1 | 12.7
| blue | GND | | E11 S6.1 | A11 TP3.1 | 10.2
| blue | GND | | A11 TP3.1 | D16 B1.1 | 86.4
| blue | GND | | D16 B1.1 | Z16 B2.1 | 10.2
| blue | GND | | Z16 B2.1 | V16 B3.1 | 10.2
| blue | GND | | V16 B3.1 | R16 B4.1 | 10.2
| blue | GND | | R16 B4.1 | O16 B8.1 | 7.6
| blue | GND | | O16 B8.1 | K16 B7.1 | 10.2
| blue | GND | | K16 B7.1 | G16 B6.1 | 10.2
| blue | GND | | G16 B6.1 | C16 B5.1 | 10.2
| blue | GND | | C16 B5.1 | B23 J_TEENSY_A.1 | 81.3
| blue | GND | | B23 J_TEENSY_A.1 | A29 J_TEENSY_B.2 | 17.8
| blue | GND | | A29 J_TEENSY_B.2 | N29 J_TEENSY_B.15 | 33.0
| blue | GND | | N29 J_TEENSY_B.15 | X35 J1.5 | 40.8
| blue | GND | | X35 J1.5 | I35 J2.5 | 38.1
| blue | GND | | I35 J2.5 | Z44 CB1.4 | 66.0
| blue | GND | | Z44 CB1.4 | U44 CB2.4 | 12.7
| blue | GND | | U44 CB2.4 | P44 CB3.4 | 12.7
| blue | GND | | P44 CB3.4 | K44 CB4.4 | 12.7
| blue | GND | | K44 CB4.4 | F44 CB5.4 | 12.7
| blue | GND | | F44 CB5.4 | Z46 CB1.2 | 55.8
| blue | GND | | Z46 CB1.2 | U46 CB2.2 | 12.7
| blue | GND | | U46 CB2.2 | P46 CB3.2 | 12.7
| blue | GND | | P46 CB3.2 | K46 CB4.2 | 12.7
| blue | GND | | K46 CB4.2 | F46 CB5.2 | 12.7
| red | +3V3 | | A10 TP4.1 | D10 S1.2 | 73.7
| red | +3V3 | | D10 S1.2 | Y10 S2.2 | 12.7
| red | +3V3 | | Y10 S2.2 | T10 S3.2 | 12.7
| red | +3V3 | | T10 S3.2 | O10 S4.2 | 12.7
| red | +3V3 | | O10 S4.2 | J10 S5.2 | 12.7
| red | +3V3 | | J10 S5.2 | E10 S6.2 | 12.7
| red | +3V3 | | E10 S6.2 | M13 R12.2 | 27.9
| red | +3V3 | | M13 R12.2 | H13 R13.2 | 12.7
| red | +3V3 | | H13 R13.2 | N23 J_TEENSY_A.15 | 40.6
| red | +3V3 | | N23 J_TEENSY_A.15 | Z29 J_TEENSY_B.3 | 45.7
| red | +5V | | A09 TP5.1 | D09 S1.3 | 73.7
| red | +5V | | D09 S1.3 | Y09 S2.3 | 12.7
| red | +5V | | Y09 S2.3 | T09 S3.3 | 12.7
| red | +5V | | T09 S3.3 | O09 S4.3 | 12.7
| red | +5V | | O09 S4.3 | J09 S5.3 | 12.7
| red | +5V | | J09 S5.3 | E09 S6.3 | 12.7
| red | +5V | | E09 S6.3 | B29 J_TEENSY_B.1 | 109.1
| yellow | SDA | | A08 TP1.1 | D08 S1.4 | 73.8
| yellow | SDA | | D08 S1.4 | Y08 S2.4 | 12.7
| yellow | SDA | | Y08 S2.4 | T08 S3.4 | 12.7
| yellow | SDA | | T08 S3.4 | O08 S4.4 | 12.7
| yellow | SDA | | O08 S4.4 | J08 S5.4 | 12.7
| yellow | SDA | | J08 S5.4 | E08 S6.4 | 12.7
| yellow | SDA | | E08 S6.4 | Q13 R12.1 | 43.1
| yellow | SDA | | Q13 R12.1 | T29 J_TEENSY_B.9 | 48.3
| yellow | SCL | | A07 TP2.1 | D07 S1.5 | 73.8
| yellow | SCL | | D07 S1.5 | Y07 S2.5 | 12.7
| yellow | SCL | | Y07 S2.5 | T07 S3.5 | 12.7
| yellow | SCL | | T07 S3.5 | O07 S4.5 | 12.7
| yellow | SCL | | O07 S4.5 | J07 S5.5 | 12.7
| yellow | SCL | | J07 S5.5 | E07 S6.5 | 12.7
| yellow | SCL | | E07 S6.5 | L13 R13.1 | 32.9
| yellow | SCL | | L13 R13.1 | U29 J_TEENSY_B.8 | 63.5
| orange | D0 | B1 | D15 B1.2 | A23 J_TEENSY_A.2 | 27.9
| orange | D1 | B2 | Z15 B2.2 | Z23 J_TEENSY_A.3 | 20.3
| green | D4 | B3 | V15 B3.2 | W23 J_TEENSY_A.6 | 22.8
| white | D8 | B4 | R15 B4.2 | S23 J_TEENSY_A.10 | 22.8
| orange | D32 | B5 | C15 B5.2 | E23 J_TEENSY_A.24 | 25.4
| green | D30 | B6 | G15 B6.2 | G23 J_TEENSY_A.22 | 20.3
| green | D26 | B7 | K15 B7.2 | K23 J_TEENSY_A.18 | 20.3
| orange | D9 | B8 | O15 B8.2 | R23 J_TEENSY_A.11 | 27.9
| white | D23 | CB1 | Z47 CB1.1 | Y29 J_TEENSY_B.4 | 48.3
| orange | LED_ARM | | Z45 CB1.3 | A45 R1.1 | 2.6
| orange | D6 | CB2 | U47 CB2.1 | U23 J_TEENSY_A.8 | 61.0
| white | LED_EN | | U45 CB2.3 | T45 R2.1 | 2.6
| white | D14 | CB3 | P47 CB3.1 | P29 J_TEENSY_B.13 | 45.7
| orange | LED_SFT | | P45 CB3.3 | Q45 R3.1 | 2.6
| white | D38 | CB4 | K47 CB4.1 | J29 J_TEENSY_B.19 | 48.3
| green | LED_CONF | | K45 CB4.3 | L45 R4.1 | 2.6
| green | D34 | CB5 | F47 CB5.1 | F29 J_TEENSY_B.23 | 45.7
| white | LED_ALT | | F45 CB5.3 | E45 R5.1 | 2.6
| orange | D22 | J1.1 | X39 J1.1 | X29 J_TEENSY_B.5 | 25.4
| orange | D21 | J1.2 | X38 J1.2 | W29 J_TEENSY_B.6 | 25.4
| orange | D20 | J1.3 | X37 J1.3 | V29 J_TEENSY_B.7 | 25.5
| green | D16 | J1.4 | X36 J1.4 | R29 J_TEENSY_B.11 | 33.1
| orange | D37 | J2.1 | I39 J2.1 | I29 J_TEENSY_B.20 | 25.4
| white | D39 | J2.2 | I38 J2.2 | K29 J_TEENSY_B.18 | 28.0
| orange | D40 | J2.3 | I37 J2.3 | L29 J_TEENSY_B.17 | 28.0
| green | D41 | J2.4 | I36 J2.4 | M29 J_TEENSY_B.16 | 28.1
| orange | D33 | NP1.1 | B30 NP1.1 | E29 J_TEENSY_B.24 | 10.2
| orange | D35 | NP1.2 | B29 NP1.2 | G29 J_TEENSY_B.22 | 12.7
| orange | D36 | NP1.3 | B28 NP1.3 | H29 J_TEENSY_B.21 | 17.7
| orange | D10 | NP1.4 | B27 NP1.4 | Q23 J_TEENSY_A.12 | 48.4
| white | D28 | NP1.5 | B26 NP1.5 | I23 J_TEENSY_A.20 | 25.6
| white | D25 | NP1.6 | B25 NP1.6 | L23 J_TEENSY_A.17 | 30.7
| green | D24 | NP1.7 | B24 NP1.7 | M23 J_TEENSY_A.16 | 30.7
| orange | D11 | NP1.8 | B23 NP1.8 | P23 J_TEENSY_A.13 | 35.8
| orange | D5 | LED1 | A41 R1.2 | V23 J_TEENSY_A.7 | 58.4
| orange | D17 | LED2 | T41 R2.2 | S29 J_TEENSY_B.10 | 33.0
| white | D15 | LED3 | Q41 R3.2 | Q29 J_TEENSY_B.12 | 30.5
| green | D13 | LED4 | L41 R4.2 | O29 J_TEENSY_B.14 | 38.1
| white | D29 | LED5 | E41 R5.2 | H23 J_TEENSY_A.21 | 53.3
| yellow | IRQ1 | | D06 S1.6 | Y23 J_TEENSY_A.4 | 55.7
| yellow | IRQ2 | | Y06 S2.6 | X23 J_TEENSY_A.5 | 45.5
| yellow | IRQ3 | | T06 S3.6 | T23 J_TEENSY_A.9 | 43.0
| yellow | IRQ4 | | O06 S4.6 | O23 J_TEENSY_A.14 | 43.0
| yellow | IRQ5 | | J06 S5.6 | J23 J_TEENSY_A.19 | 43.0
| yellow | IRQ6 | | E06 S6.6 | F23 J_TEENSY_A.23 | 45.5

Nothing matches that filter.

107 of 107 shown. On the board these 107 connections become 223 modelled jumper legs, because a run that changes both row and column is drawn as two straight legs meeting at a corner hole, and a run that would lie on top of another wire is detoured around it. Electrically each is still one connection — one length of wire, bent, will do it.

## Revision notes

How this layout got here

GPIO assignment (2026-08-26). Connector signals are not in sequential blocks. Each one is wired to a Teensy pin chosen for physical proximity, solved as an assignment problem over the free GPIOs, which is why the numbers look scattered. Eighteen signals override proximity because they are already soldered and stay put: B1–B8 (D0 D1 D4 D8 / D32 D30 D26 D9), J1/J2 (D22 D21 D20 D16 / D37 D39 D40 D41, on the D13–D23 / D33–D41 rail — row 29 here) and LED4/LED5 (D13 / D29, their resistors jumpered L41→O29 and E41→H23). The other 22 — the six IRQs, the five control buttons, three of the five lamps and the eight numpad lines — moved to their nearest free pin. Firmware pin constants must follow this map (scripts/pin_map.json); the tables on this page, the schematic and the manufactured board are all generated from it.

Teensy orientation, verified against the board (2026-08-26). Two earlier revisions of this page had the module in wrong — once with the rows swapped, once with both rows reversed. It plugs in USB toward the B23/B29 end (the left edge of the header strips below), and each socket carries its Teensy row in that row's own order, neither reversed: row 23 runs GND D0 D1 … D12 +3V3 D24 … D32 left to right, row 29 runs +5V GND +3V3 D23 D22 … D13 GND D41 … D33. Three independent readings off the physical board agree: the Vin/GND/3.3V trio sits in B29 A29 Z29, B1's wire is in A23 (D0) and B2's in Z23 (D1) — exactly the firmware's pins. Every already-soldered wire keeps both its GPIO and its hole under this mapping. If this is ever doubted again, settle it by reading a hole off the board, never by checking whether the resulting map looks sensible — every table on this page is generated from the mapping, so a wrong one still looks self-consistent.

R4's jumper was moved off J1's pin (resolved). R4's LED wire had gone into L41→R29, but R29 reads D16 — J1 pin 4, already soldered. It has been pulled and re-landed five holes along in O29 (D13), so LED4 is now frozen on D13 alongside LED5's E41→H23 (H23 = D29). D13 also drives the Teensy's onboard LED, which is harmless here precisely because LED4 is a driven output — never put a pulled-up input on it.

Connector standard. S1–S6 follow the XH2.54 6-pin Haptic Console Connector Standard v1.1 — pin 1 GND, pin 2 3.3V, pin 3 5V, pin 4 SDA, pin 5 SCL, pin 6 IRQ — matching cables crimped to that spec.

Group layout. Every JST group shares one anchor row, mirrored left/right to match the physical panel (S1–S6 centred; B1–B4 mirrors B5–B8; J1 mirrors J2; CB1–CB5 near-symmetric about the centre column). Because each group shares an anchor row, the same pin number lands on the same row across the group, which is what makes the single-wire bus rails possible. Everything fits inside the physical 32×50 hole grid.

Moves since the first revision. The Teensy sockets moved one column left and two rows up (rows 25→23 and 31→29) and R12/R13 shifted two columns; S1–S6 shifted one column left to clear the TP1–TP5 header at the right edge; R1–R5 went from lying flat across row 48 to standing upright on rows 45/41 in the column beside their own CB, which is what shortened every LED-cathode jumper to one hole.

The KiCad files match this page (2026-08-26). Everything is now generated from the same scripts/pin_map.json: the perfboard has R1–R5 standing on rows 45/41 as rewired by hand (R1 A45/A41, R2 T45/T41, R3 Q45/Q41, R4 L45/L41, R5 E45/E41) with the modelled jumper legs on the back layer, the schematic's net labels carry each signal's GPIO name, and the manufactured board has been re-netted and re-routed from scratch (0 DRC violations, 0 unconnected pads) with fresh gerbers. Change a pin by editing the generator and re-running the pipeline — never by hand-editing this page or a KiCad file.

Generated by scripts/gen_wiring_guide.py from scripts/pin_map.json and the pad positions in scripts/board_model.json — don't hand-edit this file, regenerate it. Grid refs use the board's own printed columns (F E D C B A Z Y X…G F E D C B A) and rows (01–50). GND and +5V are fully available on the main sockets; the Teensy's USB-Host and Ethernet auxiliary pads are not needed.

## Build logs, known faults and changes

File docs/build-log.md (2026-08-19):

# 2026-08-19

## Perfboard design for Control Unit (M6)

Built full placement + wiring matrix for the Control Unit perfboard, per Speedy's spec in #dissertation.

**Component mapping (confirmed against Control Unit Pin Map note, updated 2026-07-29):**
- 8x 2-pin JST-XH = action buttons B1-B8 (J1/J2 diamond clusters) → D20-D27, INPUT_PULLUP, other side GND
- 5x 4-pin JST-XH = illuminated command buttons CB1-CB5 (ARM/EN/SFT/CONF/ALT): switch → D10-D14, LED anode via 220R (R1-R5) → D8/D9/D36/D37/D38 (PWM), cathodes + switch GND → GND
- 2x 5-pin JST-XH = arcade joysticks J1/J2: U/D/L/R → D0-D7, pin 5 = common GND (digital, per pin map; the resistor-divider note is a seedling alternative, not used)
- 1x 8-pin JST-XH = 4x4 numpad NP → D28-D35 (rows+cols, scan in software)
- Teensy 4.1 in 2x24 female headers, USB faces left
- I2C rail: 6x 8-pin JST-XH slots (per Connector Standard signals): GND/5V/3V3/SDA/SCL shared bus; IRQ per slot → D15/D16/D17/D39/D40/D41; RESET shared → onboard RESET button → GND; ID → 10k → 3V3 (R6-R11). SDA/SCL pullups 4k7 (R12-R13) at rail head.
- Board: 200x120 mm perfboard, all JST-XH, pin 1 = leftmost. Resistor tally 13.

**Note:** Pin map says I2C on D18(SCL)/D19(SDA) — newer than the 2026-07-15 memory (GP17/GP16 = Wire1). Flagged to Speedy: if firmware uses Wire1, move only those two bus wires.

**Artifacts:** `.openclaw/tmp/perfboard/` → layout.tex/matrix.tex (+ .pdf, .svg, .png 300dpi). Rendered with pdflatex (basic TeX Live 2026: NO helvet, NO T1/fontenc, NO pattern=dots — missing fonts; use OT1 CM sans).

**Open question:** confirm Wire vs Wire1 for the rail bus pins.

**Update (11:22):** Speedy sent CLAUDE.md + README from the firmware repo (PlatformIO workspace). Key facts: 19-byte ModulePacket, I2C addresses 0x20/0x21/0x22 (loadcell/pressure/encoder), IRQ on GP6, ID pin sampled but UNUSED in logic → **"no resistor ladder, it's useless"** → removed R6-R11 from perfboard design. Resistor tally now 7 (5x 220R + 2x 4k7). Matrix/layout updated: ID pins not wired.

**Discrepancy flagged:** bring-up harness in main.cpp uses buttons pins 2-4, joystick 5-8, keypad 24-31 (keypad connector reversed, pins 1+10 NC); Control Unit Pin Map (final) uses D0-D7/D10-D14/D20-D27/D28-D35. Perfboard follows the pin map; asked Speedy to confirm.

**MIDI mapping (from README):** CC1-5 ch1 = flywheel velocity/direction, pneumatic pressure, spring tension/acoustic; ch16 notes = numpad 36-45, action 46-53, control 54-58. MIDI 2.0 planned on UMP group 1.

**obsidian-manager:** spawned with 3 note drafts (firmware architecture, perfboard v2, panel input bring-up + connector pinouts).

## SPICE files (11:24)

Created 4 SPICE circuits in `.openclaw/tmp/perfboard/spice/` (each `.cir` + `.asc` + README.txt):
- **pressure_conditioning**: MPX5010DP -> 10k/22k divider -> Pico ADC. 0.2V -> 0.1375V, 4.7V -> 3.23V, ~0.31 V/kPa. Fills the "conditioning not yet designed" gap in firmware README.
- **loadcell_bridge**: 350R full bridge, 5V exc, dR sweep 0-0.7R -> 0-10mV differential (2mV/V scale). Opposite arms diverge: R1/R4 +dR, R2/R3 -dR.
- **i2c_pullup_rise**: 4.7k pullup + 150pF + open-drain switch model -> 30-70% trise 596ns (fits 400kHz). Note: initial Rdrv-to-rail model was wrong (parallel charge path gave 12ns); proper SW model fixed it.
- **joystick_divider**: 10k pullup + 470R/2.2k -> idle 3.30V, left 0.148V, right 0.595V.

**ngspice gotchas learned (verified by running):**
- installed via brew (no X11 needed for batch `-b`)
- first netlist line = title (even comments), so always start with a `* comment`
- `{}` preprocessor is arithmetic-only: `{350-d}` FAILS, `if()` unsupported in braces/.param
- use `.control` + `alter @dev[resistance]` + `echo` instead (full expression evaluator)
- `.meas TRAN` needs `TRIG v(x) VAL=0.99` form (not `v(x)=0.99`)
- `.tran` needs explicit tstep: `.tran 1n 40u`, not `.tran 0 40u` (LTspice-only)
- LTspice `.asc` keeps the friendly syntax ({if(...)}, .tran 0) - unverified, user opens in LTspice

## Perfboard v2 (big board) - mosher style

Speedy shared a photo of his actual board (brown phenolic, white silk zones, numbered 30-row terminal strip on the left) + YouTube video "Wiring for proto board" (mosher, UCF/GaTech) for inspiration. Redesigned layout as layout-big.tex.

**Board assumed 250x200 mm** (told him to give exact dims for a re-fit).

**Video-inspired techniques applied:**
- Strip rows 1-3 = GND/5V/3V3 power buses, bridged to 3 vertical bus lines running down the board
- Zone-based layout matching his silk-screened zones (white zone borders on tan board)
- Resistors bridge into rails: 220R LEDs (R1-R5), 10k ID (R6-R11), 4k7 pullups (R12-R13)
- S-curve jumper example drawn (22 AWG, pre-bend, avoid overlaps)
- Teensy socketed in 2x24 female headers, USB left
- Wiring unchanged (same matrix as v1)

**Render pipeline lesson:** TeX Live 2026basic has NO helvet (phvr7t/phvr8t missing) and NO ecsx/EC small-size fonts. Use OT1 default + cmss only, no fontenc, no pattern=dots. Verified with image checks after each iteration.

## KiCad MCP servers added (12:42)

Speedy installed KiCad 10.0.5 (brew, /Applications/KiCad + kicad-cli 10.0.5) and added two MCP servers to openclaw.json:
- `kicad-mcp` (ANamelessDrake, venv at agents/administrator/tools/kicad-mcp, pip editable install)
- `kicad-mcp-server` (Seeed, agents/administrator/tools/kicad-mcp-server, pip editable install)

Gateway restarted on request (LaunchAgent, port 18789). Verified via JSON-RPC initialize handshake that both server binaries start (kicad-mcp-server logs "Starting MCP server"; kicad-mcp starts, only a harmless pydantic IncompleteFieldDefinitionWarning). Log warning "env PYTHONPATH is blocked for stdio startup safety" is BENIGN: both packages are pip-installed editable in their venvs, so no PYTHONPATH needed.

**Session caveat:** this Discord session's toolset predates the MCPs; kicad-* tools load in a fresh session. Test = ask for a KiCad task; if tools absent, open new session.

**Planned use once live:** generate Control Unit .kicad_sch from perfboard matrix (kicad-mcp), export netlist via kicad-cli, diff pin-by-pin vs matrix as evidence check; then module boards (pressure divider, load cell) from the SPICE specs.

**VeriClaw note:** "VeriClaw route activated" fired this turn; vericlaw skill read (~/.openclaw/plugin-skills/vericlaw). Correction-companion discovery skill; mentioned once to Speedy, no install requested.

## Control Unit KiCad Schematic — COMPLETE & VERIFIED (14:10)

Built the full Control Unit (M6) schematic with the kicad MCP toolchain, MCP-only (per Speedy's rule: NEVER python-edit KiCad files).

**Result: 164/164 wiring pins match the perfboard matrix — zero mismatches.**

### Deliverables (in .openclaw/tmp/kicad/)
- `haptic-console-control-unit.kicad_sch` — the schematic (paren balance 0, loads clean)
- `sym-lib-table` + `fp-lib-table` — now point at installed KiCad libs + XenGi teensy
- Renders in `render/`: cu_schematic_full.png (4000px), detail crops (teensy/rails/buttons/numpad), pcb_view.png
- XenGi `teensy.kicad_sym` + `Teensy41.kicad_mod` installed into KiCad's shared dirs

### THE MIRROR RULE (critical, cost ~2h)
This MCP toolchain + KiCad resolves symbol pins Y-mirrored: `abs_y = inst_y - rel_y`.
All labels/power symbols/no-connects must be placed at mirrored positions:
`y_mirrored = 2 * inst_y - y_nominal`. Verified via bare-connector netlist test
(label at nominal pin1 pos → netlist says pin5). Full writeup in memory/kicad-mcp-lessons.md.

### LED chain correction
U1 D8/D9/D36/D37/D38 pins carry D8..D38 labels (net U1→resistor), LED_ARM/EN/SFT/CONF/ALT
nets only between CB pin3 and R pin1. Matches matrix: "LED anode via 220R → D8/D9/D36-38".

### ERC state
- 2 expected "Input Power pin not driven" (no PSU symbol; power via Teensy VIN)
- ~30 cosmetic library-table warnings (GUI resolves)
- kicad-cli "annotation errors" warning persists (harmless; GUI clears on save)

### Remaining
- [ ] Nudge label positions in GUI (cosmetic overlap at pin tips)
- [ ] sync_schematic_to_pcb + board layout
- [ ] Module boards (Hybrid Bridge, Pneumatic, Spring) with same proven flow
- [ ] Vault note delegation to obsidian-manager (subagent spawned ~14:10)

## 2026-08-19 14:35 — Render fix round 3
- Board outline corrected to 300×200mm (was Arduino template ~100×100)
- All 30 components placed inside outline; S1-S6 (8-pin JST XH) moved x=285→275 to clear the edge
- 3D render verified: clean board, no overhangs, Teensy 4.1 footprint present
- U1 reference shows "REF**" — kicad-cli fp upgrade cannot convert legacy XenGi Teensy41.kicad_mod; female headers left empty, to be finished later (per Andrei)
- 2D composite uses per-layer SVG export with --page-size-mode 2 (board-only), threshold mask compositing

## 2026-08-19 14:50 — Pipeline upgrade round
- **teensy.pretty upgraded to modern format**: `kicad-cli fp upgrade <dir> -o <newdir>` WORKS when given a directory (earlier failures were file-path misuse). All 12 XenGi footprints → version 20260206, 3D model preserved, installed to KiCad shared support
- **U1 fixed**: re-placed with modern Teensy41 footprint → reference now "U1" (was REF**), 67 pads, 3D model renders
- **J1/J2 nets assigned**: J1 = /D0-/D3 + GND, J2 = /D4-/D7 + GND (per schematic)
- **MCP servers**: both at latest upstream (kicad-mcp 24dd380, kicad-mcp-server 25dad7f)
- **New libraries added** (to ~/Library/Preferences/kicad/):
  - Digi-Key `digikey-kicad-library` (13MB shallow, 464 footprints modernized via fp upgrade, atomic parts w/ 3D models)
  - SparkFun `SparkFun-KiCad-Libraries` (265MB, 21 footprint libs + 40+ symbol libs; HX711 symbol in SparkFun-Sensor)
  - Both wired into project fp-lib-table + sym-lib-table
- **4K 3D render verified**: Teensy 4.1 fully visible (headers, chip, SD slot, Ethernet pads), all components inside 300×200 outline

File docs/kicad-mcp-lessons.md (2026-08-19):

# KiCad MCP — Hard-Won Lessons (2026-08-19)

## THE RULE (from Speedy, emphatic)

**NEVER modify KiCad schematic/PCB files with python or manual text edits. ALWAYS use the MCP tools** (`kicad-mcp__*` / `kicad-mcp-server__*`). Every file is MCP-owned. Hand-editing breaks the round-trip and wastes hours.

## What went wrong (Control Unit rebuild, 2026-08-19)

1. **Python-appended power symbols broke connectivity.** I appended `(symbol ... (lib_id "power:GND") ...)` instances by python. They parsed "fine" (paren balance 0) but showed `<NO NET>` in netlists and kicad-cli eventually refused to load the file ("Failed to load schematic").
2. **Root cause found:** KiCad 9/10 symbol instances need per-pin entries `(pin "1" (uuid "..."))` inside each instance, plus full property sets (Reference/Value/Footprint/Datasheet). My hand-written blocks lacked them; the MCP-written ones have them. The MCP writer is the only correct writer.
3. **MCP tools only round-trip their own writes.** Any python edit, even "correct", gets mangled by the next MCP call's full-file rewrite (annotate, delete, etc.).
4. **The native batch tool** `kicad-mcp__schematic_add_power_symbols` places power symbols in the correct format — use it, never hand-append.
5. **Annotate is the last step** for `#PWR?` refs — annotate assigns `#PWR1..N`. Run it once, after all placement, and don't touch the file afterwards except via MCP.

## Correct workflow for building a schematic with these MCPs

1. `kicad-mcp-server__create_kicad_project` (fresh template project).
2. Extract template junk UUIDs (read-only python is fine for READING/parsing — never writing) → delete via `kicad-mcp__schematic_delete_many` (one atomic call).
3. Add custom lib symbols via `kicad-mcp__schematic_add_lib_symbol` (pins as structured list).
4. Place everything via `kicad-mcp__schematic_place_symbol` / `schematic_place_footprint`.
5. Labels via `kicad-mcp__schematic_add_labels` (atomic batch).
6. Power symbols via `kicad-mcp__schematic_add_power_symbols` (atomic batch — correct format guaranteed).
7. No-connects via `kicad-mcp__schematic_add_no_connects`.
8. Annotate → ERC (`kicad-mcp__schematic_run_erc`) → export netlist via kicad-cli → validate.
9. `kicad-mcp__sync_schematic_to_pcb` for the PCB.

## References Speedy supplied (2026-08-19)

- JST headers on KiCad: https://www.reddit.com/r/KiCad/comments/1g5w09f/how_do_i_get_jst_headers_on_kicad/
- Teensy KiCad library (symbols + footprints): https://github.com/XenGi/teensy_library (+ https://github.com/XenGi/teensy.pretty for footprints) — covers Teensy 4.1.

## Tooling notes

- schemdraw-circuit-diagrams skill (proposal applied 2026-08-19) for circuit diagrams: `~/.openclaw/skill-workshop/proposals/schemdraw-circuit-diagrams-20260819-3e8bff1fc4/PROPOSAL.md`
- Project lives at `.openclaw/tmp/kicad/` (haptic-console-control-unit).
- kicad-cli: `/opt/homebrew/bin/kicad-cli`.
- Broken/partial builds archived in `.openclaw/tmp/kicad/broken/` and `broken2/`.

## 2026-08-19 UPDATE — MIRROR BUG SOLVED (the big one)

**THE MIRROR RULE (critical for this MCP toolchain):** KiCad resolves symbol pins at
`abs_y = inst_y - rel_y` (Y-mirrored) when symbols are embedded from the installed
KiCad 10 library into the KiCad-9-version template schematic. So EVERY label, power
symbol, and no-connect must be placed at the MIRRORED position:
`y_mirrored = 2 * inst_y - y_nominal` (equivalently `inst_y - rel_y`).

This is why build 1 "worked" (117/157) — its labels happened to be at mirrored coords.
The rebuild used nominal coords and failed until we mirrored them back.

**Verification pattern that caught it:** the netlist is ground truth. Test on a bare
Conn_01x05: label at nominal pin1 pos → netlist says pin5. That proves the mirror.

**FINAL SCHEMATIC STATE (haptic-console-control-unit, 2026-08-19 ~14:10):**
- 164/164 wiring matrix pins verified against netlist export (0 mismatches)
- Components: U1 (Teensy 4.1 XenGi symbol), B1-B8, J1/J2, CB1-CB5, NP, S1-S6, R1-R5, R12/R13
- 125 net labels, 40 power symbols, 19 no-connects, paren balance 0
- ERC: 2 expected "Input Power pin not driven" (no PSU symbol; power via Teensy VIN), 30 library-table warnings (cosmetic, GUI resolves)
- sym-lib-table + fp-lib-table now point at installed KiCad libs + XenGi teensy
- Path: .openclaw/tmp/kicad/haptic-console-control-unit.kicad_sch
- Render: .openclaw/tmp/kicad/render/cu_final.png

**LED chain correction:** U1 D8/D9/D36/D37/D38 pins carry D8..D38 labels (net U1→resistor),
while LED_ARM/EN/SFT/CONF/ALT nets are only between CB pin3 and R pin1. Matches perfboard
matrix: "LED anode via 220R (R1-R5) → D8/D9/D36/D37/D38".

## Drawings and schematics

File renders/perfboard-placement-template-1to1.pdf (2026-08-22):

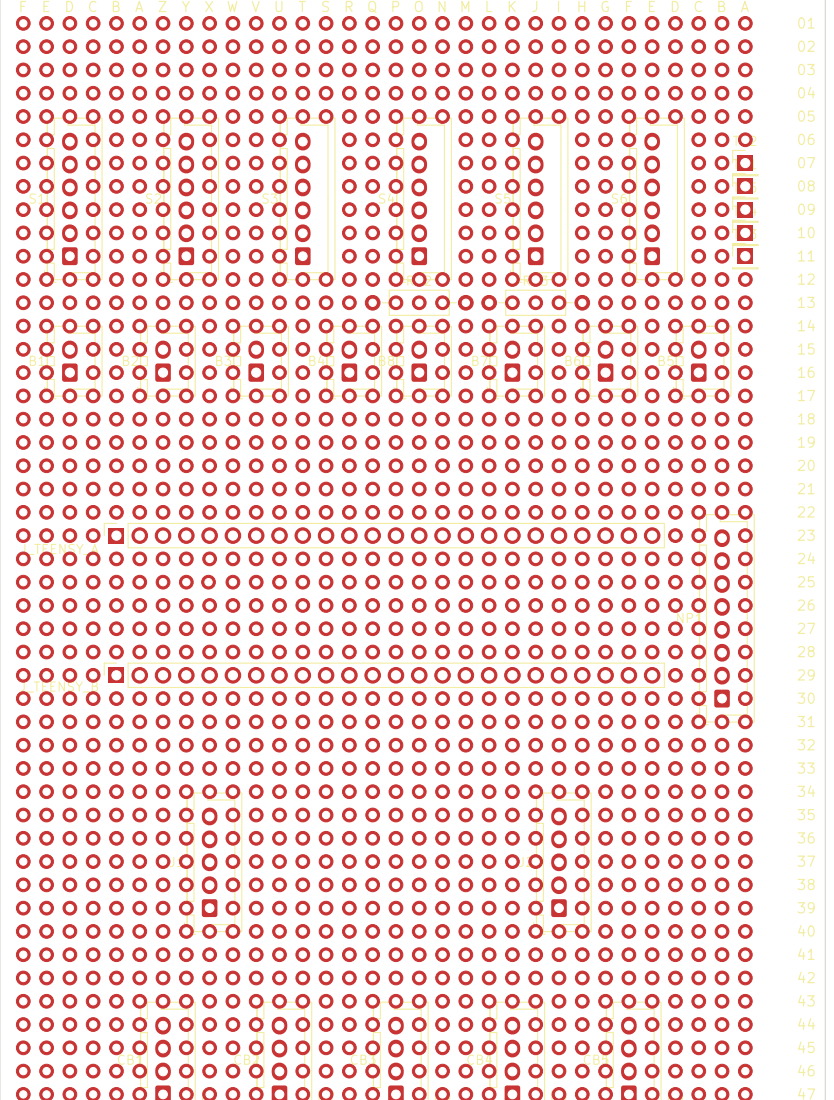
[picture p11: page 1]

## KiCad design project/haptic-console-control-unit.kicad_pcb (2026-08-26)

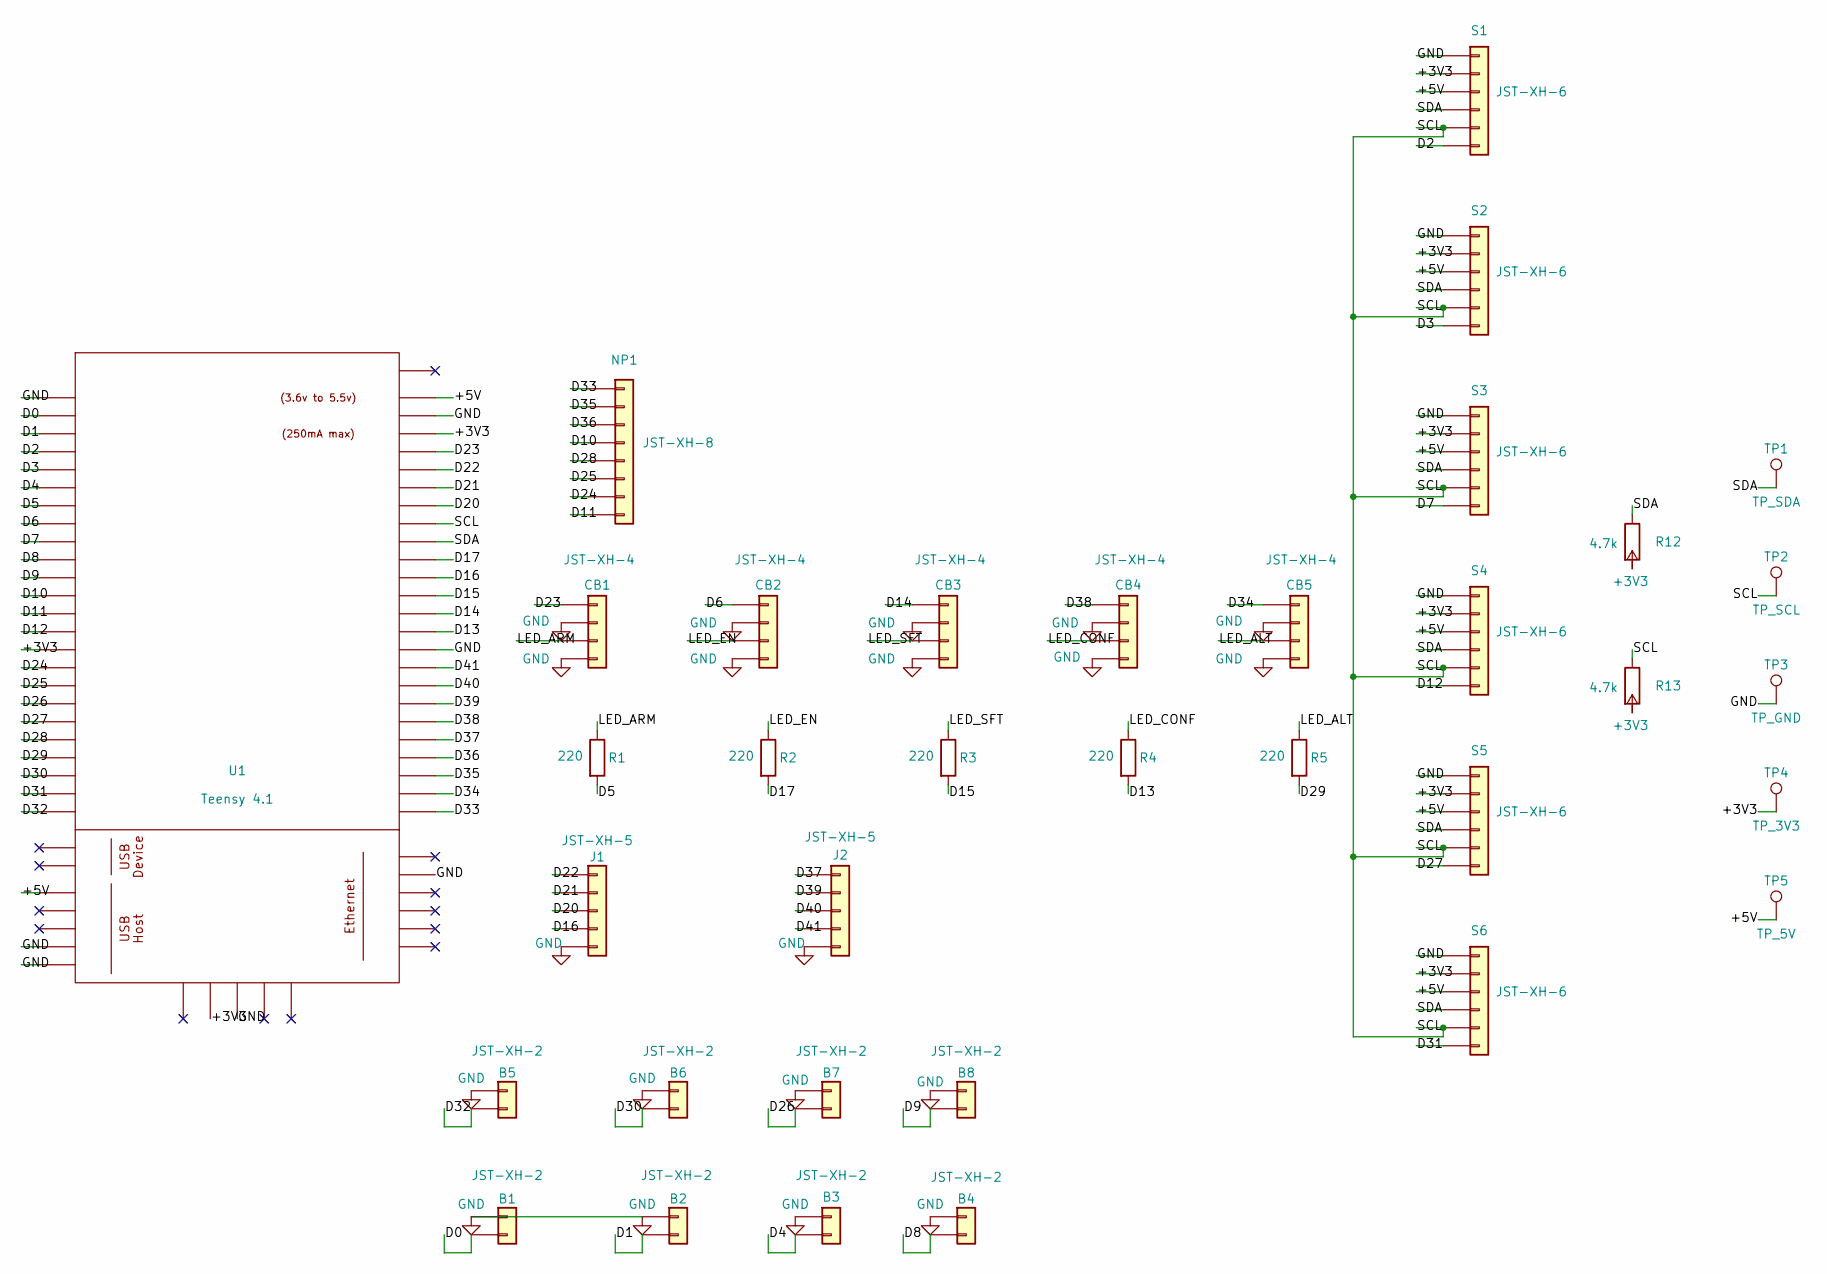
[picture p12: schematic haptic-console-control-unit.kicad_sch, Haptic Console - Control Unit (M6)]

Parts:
B1, B2, B3, B4, B5, B6, B7, B8: JST-XH-2; JST_XH_B2B-XH-A_1x02_P2.50mm_Vertical
CB1, CB2, CB3, CB4, CB5: JST-XH-4; JST_XH_B4B-XH-A_1x04_P2.50mm_Vertical
J1, J2: JST-XH-5; JST_XH_B5B-XH-A_1x05_P2.50mm_Vertical
NP1: JST-XH-8; JST_XH_B8B-XH-A_1x08_P2.50mm_Vertical
R1, R2, R3, R4, R5: 220; R_Axial_DIN0207_L6.3mm_D2.5mm_P10.16mm_Horizontal
R12, R13: 4.7k; R_Axial_DIN0207_L6.3mm_D2.5mm_P10.16mm_Horizontal
S1, S2, S3, S4, S5, S6: JST-XH-6; JST_XH_B6B-XH-A_1x06_P2.50mm_Vertical
TP1: TP_SDA; TestPoint_THTPad_D1.5mm_Drill0.7mm
TP2: TP_SCL; TestPoint_THTPad_D1.5mm_Drill0.7mm
TP3: TP_GND; TestPoint_THTPad_D1.5mm_Drill0.7mm
TP4: TP_3V3; TestPoint_THTPad_D1.5mm_Drill0.7mm
TP5: TP_5V; TestPoint_THTPad_D1.5mm_Drill0.7mm
U1: Teensy 4.1; Teensy41

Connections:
+3V3: R12.2, R13.2, S1.2, S2.2, S3.2, S4.2, S5.2, S6.2, TP4.1, U1.15 (3V3), U1.46 (3V3), U1.51 (3V3)
/+5V: S1.3, S2.3, S3.3, S4.3, S5.3, S6.3, TP5.1, U1.48 (VIN), U1.55 (5V)
/D0: B1.2, U1.2 (0_RX1_CRX2_CS1)
/D1: B2.2, U1.3 (1_TX1_CTX2_MISO1)
/D2: S1.6, U1.4 (2_OUT2)
/D3: S2.6, U1.5 (3_LRCLK2)
/D4: B3.2, U1.6 (4_BCLK2)
/D5: R1.2, U1.7 (5_IN2)
/D6: CB2.1, U1.8 (6_OUT1D)
/D7: S3.6, U1.9 (7_RX2_OUT1A)
/D8: B4.2, U1.10 (8_TX2_IN1)
/D9: B8.2, U1.11 (9_OUT1C)
/D10: NP1.4, U1.12 (10_CS_MQSR)
/D11: NP1.8, U1.13 (11_MOSI_CTX1)
/D12: S4.6, U1.14 (12_MISO_MQSL)
/D13: R4.2, U1.35 (13_SCK_LED)
/D14: CB3.1, U1.36 (14_A0_TX3_SPDIF_OUT)
/D15: R3.2, U1.37 (15_A1_RX3_SPDIF_IN)
/D16: J1.4, U1.38 (16_A2_RX4_SCL1)
/D17: R2.2, U1.39 (17_A3_TX4_SDA1)
/D20: J1.3, U1.42 (20_A6_TX5_LRCLK1)
/D21: J1.2, U1.43 (21_A7_RX5_BCLK1)
/D22: J1.1, U1.44 (22_A8_CTX1)
/D23: CB1.1, U1.45 (23_A9_CRX1_MCLK1)
/D24: NP1.7, U1.16 (24_A10_TX6_SCL2)
/D25: NP1.6, U1.17 (25_A11_RX6_SDA2)
/D26: B7.2, U1.18 (26_A12_MOSI1)
/D27: S5.6, U1.19 (27_A13_SCK1)
/D28: NP1.5, U1.20 (28_RX7)
/D29: R5.2, U1.21 (29_TX7)
/D30: B6.2, U1.22 (30_CRX3)
/D31: S6.6, U1.23 (31_CTX3)
/D32: B5.2, U1.24 (32_OUT1B)
/D33: NP1.1, U1.25 (33_MCLK2)
/D34: CB5.1, U1.26 (34_RX8)
/D35: NP1.2, U1.27 (35_TX8)
/D36: NP1.3, U1.28 (36_CS)
/D37: J2.1, U1.29 (37_CS)
/D38: CB4.1, U1.30 (38_CS1_IN1)
/D39: J2.2, U1.31 (39_MISO1_OUT1A)
/D40: J2.3, U1.32 (40_A16)
/D41: J2.4, U1.33 (41_A17)
/LED_ALT: CB5.3, R5.1
/LED_ARM: CB1.3, R1.1
/LED_CONF: CB4.3, R4.1
/LED_EN: CB2.3, R2.1
/LED_SFT: CB3.3, R3.1
/SCL: R13.1, S1.5, S2.5, S3.5, S4.5, S5.5, S6.5, TP2.1, U1.41 (19_A5_SCL)
/SDA: R12.1, S1.4, S2.4, S3.4, S4.4, S5.4, S6.4, TP1.1, U1.40 (18_A4_SDA)
GND: B1.1, B2.1, B3.1, B4.1, B5.1, B6.1, B7.1, B8.1, CB1.2, CB1.4, CB2.2, CB2.4, CB3.2, CB3.4, CB4.2, CB4.4, CB5.2, CB5.4, J1.5, J2.5, S1.1, S2.1, S3.1, S4.1, S5.1, S6.1, TP3.1, U1.1 (GND), U1.34 (GND), U1.47 (GND), U1.52 (GND), U1.58 (GND), U1.59 (GND), U1.64 (GND)

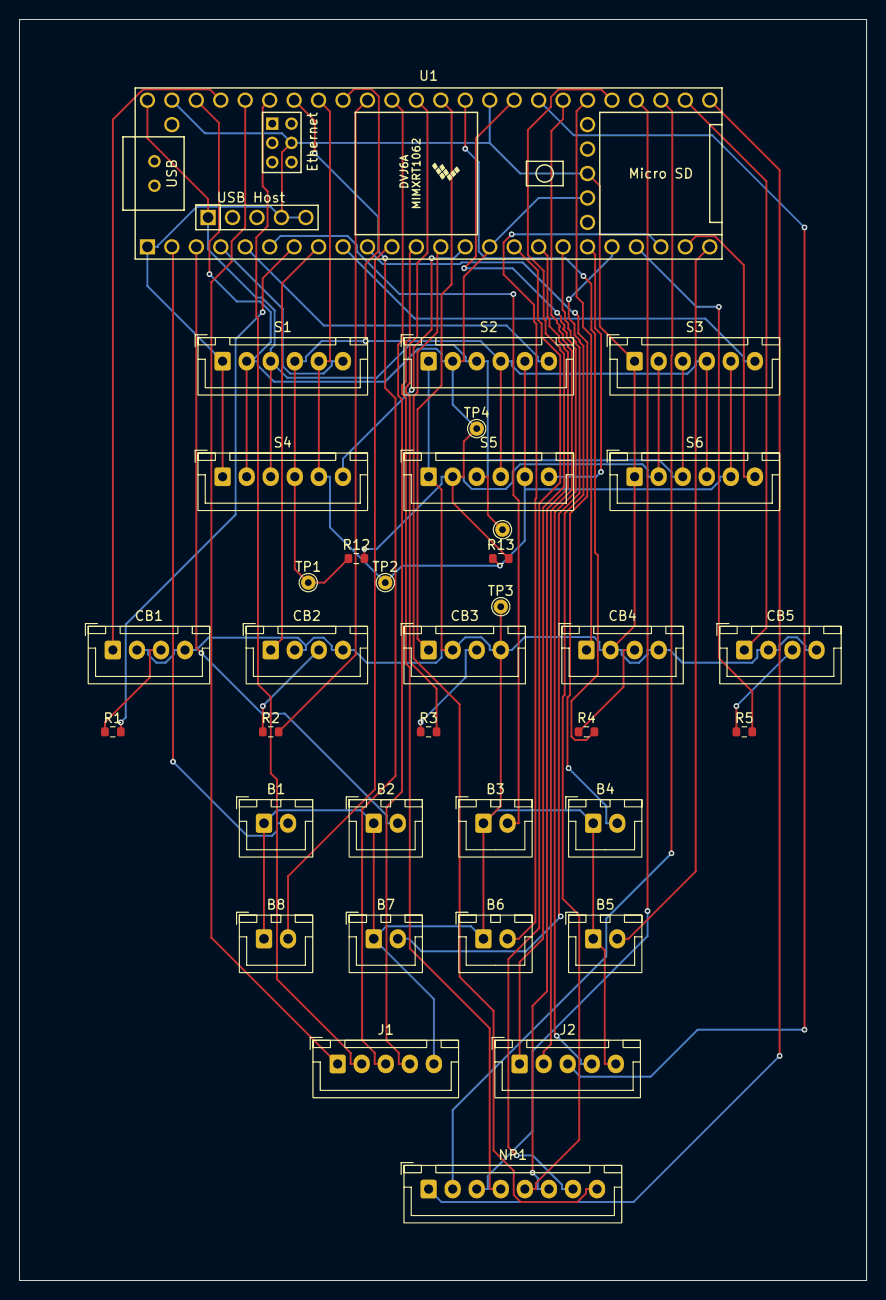
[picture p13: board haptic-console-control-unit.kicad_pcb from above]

Board: 2 copper layers, 88.0 x 131.0 mm, 35 parts (0 on the bottom side), 50 nets.

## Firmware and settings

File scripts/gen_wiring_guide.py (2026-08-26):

#!/usr/bin/env python3
"""Generate docs/wiring-guide.html from scripts/pin_map.json + board_model.json.

The page used to hand-encode the same pin mapping twice -- once in the header
pinout arrays, once per connector card -- which is exactly what drifted out of
sync in earlier revisions. Everything factual on the page now comes from
wiring_model.py, so a pin change lands in one file.

Prose is still written by hand and lives in this script.

Run from the repo root:  python3 scripts/gen_wiring_guide.py
Then:                    python3 scripts/gen_wiring_svg.py   (fills the diagram)
"""
import json
import pathlib
import sys

sys.path.insert(0, str(pathlib.Path(__file__).resolve().parent))
import wiring_model as M                                       # noqa: E402

ROOT = pathlib.Path(__file__).resolve().parent.parent
OUT = ROOT / "docs" / "wiring-guide.html"

KIND_LABEL = {"power": "power", "gnd": "ground", "i2c": "I²C / IRQ",
              "signal": "signal"}
SWATCH = {"red": "#c23b2e", "blue": "#2f5fb0", "yellow": "#c99a1e",
          "white": "#e0e0e0", "orange": "#e8912f", "green": "#3f9142"}

TYPE_OF = {"S": "JST-XH-6", "B": "JST-XH-2", "CB": "JST-XH-4", "J": "JST-XH-5",
           "NP": "JST-XH-8"}


# --- small helpers ----------------------------------------------------------
def chip(rp):
    """A clickable grid-ref chip. Clicking one highlights the same hole page-wide."""
    h = M.hole(rp)
    return f'<span class="grid-ref" data-hole="{rp[0]}.{rp[1]}" title="{rp[0]} pin {rp[1]}">{h}</span>'


def part_type(ref):
    pins = sorted((p for p in M.pad_xy if p[0] == ref), key=lambda p: int(p[1]))
    xs = {M.pad_xy[p][0] for p in pins}
    where = (f"col {M.col_letter(next(iter(xs)))}" if len(xs) == 1
             else f"row {round(M.pad_xy[pins[0]][1] / 2.54):02d}")
    if ref.startswith("R"):
        kind = "4.7 kΩ" if ref in ("R12", "R13") else "220 Ω"
    elif ref.startswith("TP"):
        kind = "header pin"
    else:
        kind = TYPE_OF[ref.rstrip("0123456789")]
    return f"{kind} &middot; {where}"


def destination(rp):
    """What the far end of this pad's wire is, as display text + css kind."""
    net = M.PINOUT[rp]
    kind = M.kind_of(net)
    if net in M.BUS:
        return f"{net} rail", kind
    if net.startswith("LED_"):
        other = next(r for r, n in M.PINOUT.items() if n == net and r != rp)
        arrow = "&rarr;" if rp[0].startswith("CB") else "&larr;"
        return f"{arrow} {M.refpin(other)} {chip(other)}", "signal"
    gpio = M.pin_map[net]
    return f"{gpio} &rarr; {chip(M.header_pad[gpio])}", kind


# --- generated blocks -------------------------------------------------------
def header_strip(row, ref, title, note):
    cells = []
    used = {M.pin_map[s]: s for s in M.pin_map}
    for i, name in enumerate(row, 1):
        rp = (ref, str(i))
        kind = M.kind_of(name if name in M.BUS else "x")
        if name in M.BUS:
            use = "rail"
        elif name in used:
            sig = used[name]
            pad = next(r for r, n in M.PINOUT.items() if n == sig)
            use = M.refpin(pad)
            kind = M.kind_of(sig)
        else:
            use = "&mdash;"
            kind = "free"
        cells.append(
            f'<div class="pin-cell {kind}" data-hole="{ref}.{i}"'
            f' data-q="{name} {use} {M.hole(rp)}">'
            f'<span class="pinno">{i}</span>'
            f'<span class="grid">{M.hole(rp)}</span>'
            f'<span class="net">{name}</span>'
            f'<span class="dest">{use}</span></div>')
    return (f'    <div class="header-strip">\n'
            f'      <div class="header-strip-title"><h3>{title}</h3>'
            f'<span class="note">{note}</span></div>\n'
            f'      <div class="pin-row">' + "".join(cells) + '</div>\n    </div>')


def rails_block():
    cards = []
    for net in ("GND", "+3V3", "+5V", "SDA", "SCL"):
        taps = M.bus_taps(net)
        kind = M.kind_of(net)
        body = " ".join(chip(rp) for rp in taps)
        cards.append(
            f'      <div class="rail-card" style="--rail-color:var(--{kind})" data-q="{net}">\n'
            f'        <div class="rail-name">{net} &middot; {len(taps)} taps '
            f'&middot; {M.color_of(net)} wire</div>\n'
            f'        <div class="rail-taps">{body}</div>\n      </div>')
    return "\n".join(cards)


def testpoints_block():
    tps = sorted((rp for rp in M.PINOUT if rp[0].startswith("TP")),
                 key=lambda rp: M.pad_xy[rp][1])
    cards = []
    for rp in tps:
        net = M.PINOUT[rp]
        cards.append(
            f'      <div class="rail-card" style="--rail-color:var(--{M.kind_of(net)})"'
            f' data-q="{rp[0]} {net}">'
            f'<div class="rail-name">{rp[0]} &middot; {net}</div>'
            f'<div class="rail-taps">{chip(rp)}</div></div>')
    return "\n".join(cards)


def conn_cards(refs):
    cards = []
    for ref in sorted(refs, key=lambda r: M.pad_xy[(r, "1")][0]):
        rows = []
        for pin in sorted((p[1] for p in M.pad_xy if p[0] == ref), key=int):
            rp = (ref, pin)
            net = M.PINOUT[rp]
            text, kind = destination(rp)
            rows.append(f'<tr data-q="{ref}.{pin} {net} {M.hole(rp)}">'
                        f'<td class="pin">{pin}</td>'
                        f'<td class="gridref">{chip(rp)}</td>'
                        f'<td class="net">{net}</td>'
                        f'<td class="dest {kind}">{text}</td></tr>')
        cards.append(
            f'      <div class="conn-card" data-q="{ref}">\n'
            f'        <div class="conn-head"><span class="ref">{ref}</span>'
            f'<span class="type">{part_type(ref)}</span></div>\n'
            f'        <table>' + "".join(rows) + '</table>\n      </div>')
    return "\n".join(cards)


def checklist_block(conns):
    rows = []
    for c in conns:
        key = f'{c["net"]}|{M.refpin(c["a"])}|{M.refpin(c["b"])}'
        rows.append(
            f'<tr data-kind="{c["kind"]}"'
            f' data-q="{c["net"]} {c["signal"]} {M.refpin(c["a"])} {M.refpin(c["b"])}'
            f' {M.hole(c["a"])} {M.hole(c["b"])} {c["color"]}">'
            f'<td class="tick"><input type="checkbox" data-key="{key}" aria-label="soldered"></td>'
            f'<td class="wcolor"><span class="dot" style="background:{SWATCH[c["color"]]}"></span>'
            f'{c["color"]}</td>'
            f'<td class="wnet">{c["net"]}</td>'
            f'<td class="wsig">{c["signal"] if c["signal"] != c["net"] else ""}</td>'
            f'<td class="wend">{chip(c["a"])} <span class="rp">{M.refpin(c["a"])}</span></td>'
            f'<td class="wend">{chip(c["b"])} <span class="rp">{M.refpin(c["b"])}</span></td>'
            f'<td class="wmm">{c["mm"]:.1f}</td></tr>')
    return "".join(rows)


# --- page -------------------------------------------------------------------
CSS = """
  :root {
    --bg: #f3ede2; --surface: #fffdf8; --surface-2: #ece3d3; --ink: #241c15;
    --muted: #6b5f4f; --border: #d8cbb2; --copper: #b1662f;
    --power: #a63b2e; --power-bg: #f6e2dd;
    --gnd: #4a4640; --gnd-bg: #e6e2da;
    --i2c: #8a5a17; --i2c-bg: #f1e2c4;
    --signal: #235e78; --signal-bg: #dfeaef;
    --free: #8d8272; --free-bg: #e9e4da;
    --hl: #ffd977;
    --shadow: 0 1px 2px rgba(36,28,21,0.06), 0 8px 24px rgba(36,28,21,0.05);
  }
  @media (prefers-color-scheme: dark) {
    :root:not([data-theme="light"]) {
      --bg: #17130f; --surface: #211a14; --surface-2: #2a2119; --ink: #f1e7d7;
      --muted: #a6957d; --border: #3c3025; --copper: #e0a868;
      --power: #e2897b; --power-bg: #3a221e;
      --gnd: #cfc7b8; --gnd-bg: #2c2822;
      --i2c: #e8c37e; --i2c-bg: #3a2e15;
      --signal: #8fc4de; --signal-bg: #1c2f37;
      --free: #8b7f6d; --free-bg: #241d17;
      --hl: #6a5116;
      --shadow: 0 1px 2px rgba(0,0,0,0.3), 0 12px 32px rgba(0,0,0,0.35);
    }
  }
  :root[data-theme="dark"] {
    --bg: #17130f; --surface: #211a14; --surface-2: #2a2119; --ink: #f1e7d7;
    --muted: #a6957d; --border: #3c3025; --copper: #e0a868;
    --power: #e2897b; --power-bg: #3a221e;
    --gnd: #cfc7b8; --gnd-bg: #2c2822;
    --i2c: #e8c37e; --i2c-bg: #3a2e15;
    --signal: #8fc4de; --signal-bg: #1c2f37;
    --free: #8b7f6d; --free-bg: #241d17;
    --hl: #6a5116;
    --shadow: 0 1px 2px rgba(0,0,0,0.3), 0 12px 32px rgba(0,0,0,0.35);
  }
  * { box-sizing: border-box; }
  body { margin: 0; background: var(--bg); color: var(--ink); font-family: ui-sans-serif, system-ui, sans-serif; line-height: 1.5; padding: 0 0 6rem; }
  .wrap { max-width: 1040px; margin: 0 auto; padding: 3rem 1.5rem 0; }
  header.page-head { display: flex; flex-direction: column; gap: 0.5rem; margin-bottom: 1.5rem; padding-bottom: 1.75rem; border-bottom: 3px solid var(--copper); }
  .eyebrow { font-family: ui-monospace, monospace; font-size: 0.72rem; letter-spacing: 0.14em; text-transform: uppercase; color: var(--copper); }
  h1 { font-weight: 800; font-size: clamp(2rem, 5vw, 2.7rem); margin: 0; }
  .dek { color: var(--muted); font-size: 1rem; max-width: 68ch; }
  h2 { font-weight: 700; font-size: 1.4rem; margin: 0 0 0.25rem; scroll-margin-top: 5.5rem; }
  h3 { font-weight: 600; font-size: 1.05rem; margin: 0; }
  section { margin-bottom: 3rem; scroll-margin-top: 4.5rem; }
  .wrap.main { padding-top: 2rem; }
  .section-intro { color: var(--muted); font-size: 0.92rem; max-width: 68ch; margin: 0 0 1.25rem; }
  a { color: var(--copper); text-underline-offset: 2px; }
  code { font-family: ui-monospace, monospace; font-size: 0.9em; background: var(--surface-2); padding: 0.05rem 0.3rem; border-radius: 3px; }

  /* --- sticky toolbar --- */
  .toolbar { position: sticky; top: 0; z-index: 20; background: color-mix(in srgb, var(--bg) 92%, transparent); backdrop-filter: blur(8px); border-bottom: 1px solid var(--border); }
  .toolbar-in { max-width: 1040px; margin: 0 auto; padding: 0.6rem 1.5rem; display: flex; gap: 0.75rem; align-items: center; flex-wrap: wrap; }
  .toolbar nav { display: flex; gap: 0.15rem; flex-wrap: wrap; }
  .toolbar nav a { font-size: 0.78rem; color: var(--muted); text-decoration: none; padding: 0.25rem 0.5rem; border-radius: 5px; }
  .toolbar nav a:hover { background: var(--surface-2); color: var(--ink); }
  .grow { flex: 1 1 auto; }
  #q { font-family: ui-monospace, monospace; font-size: 0.8rem; padding: 0.35rem 0.6rem; min-width: 12rem; border: 1px solid var(--border); border-radius: 6px; background: var(--surface); color: var(--ink); }
  .btn { font-size: 0.76rem; padding: 0.3rem 0.6rem; border: 1px solid var(--border); border-radius: 6px; background: var(--surface); color: var(--muted); cursor: pointer; }
  .btn:hover { color: var(--ink); }
  .progress { font-family: ui-monospace, monospace; font-size: 0.76rem; color: var(--muted); display: flex; align-items: center; gap: 0.5rem; }
  .progress .bar { width: 6rem; height: 5px; border-radius: 3px; background: var(--surface-2); overflow: hidden; }
  .progress .bar i { display: block; height: 100%; width: 0; background: var(--copper); transition: width 0.2s; }

  .legend { display: flex; flex-wrap: wrap; gap: 0.5rem 1.25rem; padding: 0.85rem 1.1rem; background: var(--surface); border: 1px solid var(--border); border-radius: 8px; box-shadow: var(--shadow); margin-bottom: 2.5rem; }
  .legend-item { display: flex; align-items: center; gap: 0.5rem; font-family: ui-monospace, monospace; font-size: 0.78rem; color: var(--muted); }
  .swatch { width: 0.65rem; height: 0.65rem; border-radius: 2px; flex: none; }
  .swatch.power { background: var(--power); } .swatch.gnd { background: var(--gnd); }
  .swatch.i2c { background: var(--i2c); } .swatch.signal { background: var(--signal); }

  .grid-ref { font-family: ui-monospace, monospace; font-weight: 700; background: var(--surface-2); border-radius: 4px; padding: 0.05rem 0.4rem; cursor: pointer; }
  .grid-ref.hl, .pin-cell.hl { outline: 2px solid var(--copper); background: var(--hl); }
  .header-strip { background: var(--surface); border: 1px solid var(--border); border-radius: 10px; box-shadow: var(--shadow); padding: 1.25rem; margin-bottom: 1.25rem; overflow-x: auto; }
  .header-strip-title { display: flex; align-items: baseline; justify-content: space-between; margin-bottom: 0.9rem; gap: 1rem; flex-wrap: wrap; }
  .header-strip-title .note { font-family: ui-monospace, monospace; font-size: 0.74rem; color: var(--muted); }
  .pin-row { display: grid; grid-template-columns: repeat(24, minmax(56px, 1fr)); gap: 3px; min-width: 1000px; }
  .pin-cell { display: flex; flex-direction: column; align-items: center; gap: 0.1rem; padding: 0.35rem 0.15rem 0.45rem; border-radius: 6px; text-align: center; }
  .pin-cell.power { background: var(--power-bg); } .pin-cell.gnd { background: var(--gnd-bg); }
  .pin-cell.i2c { background: var(--i2c-bg); } .pin-cell.signal { background: var(--signal-bg); }
  .pin-cell.free { background: var(--free-bg); }
  .pin-cell .pinno { font-family: ui-monospace, monospace; font-size: 0.6rem; color: var(--muted); opacity: 0.7; }
  .pin-cell .grid { font-family: ui-monospace, monospace; font-weight: 700; font-size: 0.78rem; }
  .pin-cell.power .grid { color: var(--power); } .pin-cell.gnd .grid { color: var(--gnd); }
  .pin-cell.i2c .grid { color: var(--i2c); } .pin-cell.signal .grid { color: var(--signal); }
  .pin-cell.free .grid { color: var(--free); }
  .pin-cell .net { font-family: ui-monospace, monospace; font-size: 0.68rem; color: var(--muted); }
  .pin-cell .dest { font-size: 0.62rem; color: var(--muted); font-family: ui-monospace, monospace; }

  .rail-grid { display: grid; grid-template-columns: repeat(auto-fit, minmax(240px, 1fr)); gap: 0.75rem; }
  .rail-card { background: var(--surface); border: 1px solid var(--border); border-left: 4px solid var(--rail-color, var(--copper)); border-radius: 8px; box-shadow: var(--shadow); padding: 0.85rem 1rem; }
  .rail-card .rail-name { font-family: ui-monospace, monospace; font-weight: 700; font-size: 0.85rem; color: var(--rail-color, var(--copper)); margin-bottom: 0.4rem; }
  .rail-card .rail-taps { font-size: 0.82rem; color: var(--muted); line-height: 1.9; }

  .zone { margin-bottom: 2.25rem; }
  .conn-grid { display: grid; grid-template-columns: repeat(auto-fill, minmax(260px, 1fr)); gap: 0.9rem; }
  .conn-card { background: var(--surface); border: 1px solid var(--border); border-radius: 8px; box-shadow: var(--shadow); overflow: hidden; }
  .conn-card .conn-head { display: flex; justify-content: space-between; align-items: baseline; padding: 0.6rem 0.85rem; background: var(--surface-2); border-bottom: 1px solid var(--border); }
  .conn-card .conn-head .ref { font-family: ui-monospace, monospace; font-weight: 700; font-size: 0.95rem; }
  .conn-card .conn-head .type { font-size: 0.66rem; color: var(--muted); font-family: ui-monospace, monospace; }
  .conn-card table { width: 100%; border-collapse: collapse; font-size: 0.78rem; }
  .conn-card td { padding: 0.35rem 0.5rem; border-top: 1px solid var(--border); }
  .conn-card td:first-child { padding-left: 0.85rem; }
  .conn-card td:last-child { padding-right: 0.85rem; }
  .conn-card tr:first-child td { border-top: none; }
  .conn-card td.pin { font-family: ui-monospace, monospace; color: var(--muted); width: 1.4rem; }
  .conn-card td.gridref { width: 3.4rem; }
  .conn-card td.net { font-family: ui-monospace, monospace; color: var(--muted); font-size: 0.72rem; }
  .conn-card td.dest { text-align: right; font-family: ui-monospace, monospace; font-weight: 500; white-space: nowrap; }
  .conn-card td.dest.power { color: var(--power); } .conn-card td.dest.gnd { color: var(--gnd); }
  .conn-card td.dest.i2c { color: var(--i2c); } .conn-card td.dest.signal { color: var(--signal); }

  .callout { background: var(--surface); border: 1px solid var(--border); border-left: 4px solid var(--copper); border-radius: 8px; box-shadow: var(--shadow); padding: 0.9rem 1.1rem; margin-bottom: 1.5rem; font-size: 0.88rem; color: var(--muted); }
  .callout strong { color: var(--ink); }
  .callout.warn { border-left-color: #d9534f; }
  details.notes { background: var(--surface); border: 1px solid var(--border); border-radius: 8px; box-shadow: var(--shadow); padding: 0.75rem 1.1rem; }
  details.notes > summary { cursor: pointer; font-weight: 600; font-size: 0.9rem; }
  details.notes .callout { box-shadow: none; margin-top: 1rem; }

  .diagram-frame { background: var(--surface); border: 1px solid var(--border); border-radius: 10px; box-shadow: var(--shadow); padding: 1rem; overflow-x: auto; }
  .diagram-frame svg { display: block; max-width: 560px; width: 100%; height: auto; margin: 0 auto; }
  .board-bg { fill: var(--surface-2); }
  .pad-dot { fill: var(--muted); opacity: 0.5; }
  .ref-label { font: 700 9px ui-monospace, monospace; fill: var(--ink); }
  .wire { opacity: 0.92; }
  .wire-power { stroke: var(--power) !important; }
  .wire-gnd { stroke: var(--gnd) !important; }
  .wire-i2c { stroke: var(--i2c) !important; }
  .wire-casing { stroke: var(--muted); opacity: 0.5; }
  .diagram-legend { display: flex; flex-wrap: wrap; gap: 0.5rem 1.25rem; margin-top: 0.9rem; font-family: ui-monospace, monospace; font-size: 0.76rem; color: var(--muted); }
  .diagram-legend span.dot { display: inline-block; width: 0.6rem; height: 0.6rem; border-radius: 50%; margin-right: 0.35rem; vertical-align: -1px; }

  /* --- checklist --- */
  .filters { display: flex; gap: 0.35rem; flex-wrap: wrap; margin-bottom: 0.9rem; }
  .filters button { font-family: ui-monospace, monospace; font-size: 0.74rem; padding: 0.28rem 0.7rem; border: 1px solid var(--border); border-radius: 999px; background: var(--surface); color: var(--muted); cursor: pointer; }
  .filters button[aria-pressed="true"] { background: var(--copper); border-color: var(--copper); color: var(--bg); }
  /* Its own scroll container, so the header row sticks to the top of the panel
     rather than to the page. `top` must be 0 here: a non-zero offset would push
     the header down from its resting position and hide the first wire. */
  .wire-table-frame { background: var(--surface); border: 1px solid var(--border); border-radius: 10px; box-shadow: var(--shadow); overflow: auto; max-height: min(72vh, 44rem); overscroll-behavior: contain; }
  table.wires { width: 100%; border-collapse: separate; border-spacing: 0; font-size: 0.8rem; min-width: 640px; }
  table.wires th { text-align: left; font-size: 0.68rem; letter-spacing: 0.08em; text-transform: uppercase; color: var(--muted); font-weight: 600; padding: 0.6rem 0.6rem; border-bottom: 1px solid var(--border); position: sticky; top: 0; z-index: 2; background: var(--surface); }
  table.wires td { padding: 0.32rem 0.6rem; border-top: 1px solid var(--border); vertical-align: middle; }
  table.wires tr.done td { opacity: 0.42; text-decoration: line-through; }
  table.wires tr.done td.tick { opacity: 1; text-decoration: none; }
  td.tick { width: 1.8rem; padding-left: 0.9rem; }
  td.tick input { width: 1rem; height: 1rem; accent-color: var(--copper); cursor: pointer; }
  td.wcolor { font-family: ui-monospace, monospace; font-size: 0.72rem; color: var(--muted); white-space: nowrap; }
  td.wcolor .dot { display: inline-block; width: 0.6rem; height: 0.6rem; border-radius: 50%; margin-right: 0.4rem; vertical-align: -1px; border: 1px solid var(--border); }
  td.wnet { font-family: ui-monospace, monospace; font-weight: 700; }
  td.wsig { font-family: ui-monospace, monospace; font-size: 0.72rem; color: var(--muted); }
  td.wend .rp { font-family: ui-monospace, monospace; font-size: 0.7rem; color: var(--muted); margin-left: 0.3rem; }
  td.wmm { font-family: ui-monospace, monospace; text-align: right; color: var(--muted); }
  .hidden { display: none !important; }
  .dim { opacity: 0.25; }
  .empty-note { padding: 1rem; color: var(--muted); font-size: 0.85rem; }
  footer { max-width: 1040px; margin: 3rem auto 0; padding: 1.5rem 1.5rem 0; border-top: 1px solid var(--border); color: var(--muted); font-size: 0.82rem; }
  @media print {
    .toolbar, .filters { display: none; }
    body { padding-bottom: 0; }
    .conn-card, .rail-card, .header-strip { break-inside: avoid; }
    .wire-table-frame { max-height: none; overflow: visible; }
  }
"""
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

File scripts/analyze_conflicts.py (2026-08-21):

"""Analyze wire-vs-wire conflicts in a segment JSON (place_wire 8-field schema).

Conflict = two segments whose tube geometries intersect/merge at the same Z tier:
  - perpendicular mid-span crossing (strictly interior, not a shared endpoint)
  - collinear overlap (same row/col with overlapping span, different nets or not
    merely touching end-to-end)
Reports every conflict, flagged SAME-TIER (= visible overlap/z-fight) or
different-tier (renders as clean over/under). Also sanity-checks that every
segment is exactly horizontal or vertical.
"""
import sys
import json
import math

EPS = 0.05  # mm tolerance; holes are 2.54mm apart, so anything tighter is noise


def load(path):
    segs = []
    for e in json.load(open(path)):
        x1, y1, x2, y2, color, label = e[:6]
        tier = e[7] if len(e) > 7 else 0
        segs.append(dict(x1=x1, y1=y1, x2=x2, y2=y2, color=color, label=label, tier=tier))
    return segs


def orient(s):
    if abs(s["y2"] - s["y1"]) < EPS:
        return "H", min(s["x1"], s["x2"]), max(s["x1"], s["x2"]), round(s["y1"], 2)
    if abs(s["x2"] - s["x1"]) < EPS:
        return "V", min(s["y1"], s["y2"]), max(s["y1"], s["y2"]), round(s["x1"], 2)
    return "D", None, None, None


def conflicts(segs):
    out = []
    for i in range(len(segs)):
        a = segs[i]
        oa, a1, a2, ac = orient(a)
        for j in range(i + 1, len(segs)):
            b = segs[j]
            ob, b1, b2, bc = orient(b)
            pt = None
            kind = None
            if oa == "D" or ob == "D":
                continue
            if oa == "H" and ob == "V":
                # horizontal a at row ac, x in [a1,a2]; vertical b at col bc, y in [b1,b2]
                if a1 + EPS < bc < a2 - EPS and b1 + EPS < ac < b2 - EPS:
                    pt, kind = (bc, ac), "cross"
            elif oa == "V" and ob == "H":
                if b1 + EPS < ac < b2 - EPS and a1 + EPS < bc < a2 - EPS:
                    pt, kind = (bc, ac), "cross"
            elif oa == ob and ac == bc:
                ov = min(a2, b2) - max(a1, b1)
                if ov > EPS:  # strictly overlapping span, not just end-to-end touch
                    kind = "collinear"
            if kind:
                out.append((i, j, kind, pt, a["tier"] == b["tier"]))
    return out


def main():
    path = sys.argv[1]
    segs = load(path)
    diag = [i for i, s in enumerate(segs) if orient(s)[0] == "D"]
    tiny = [i for i, s in enumerate(segs)
            if math.hypot(s["x2"] - s["x1"], s["y2"] - s["y1"]) < 1.0]
    print(f"{len(segs)} segments; diagonal: {diag}; sub-1mm: {tiny}")
    if diag:
        for i in diag:
            print("  diagonal seg", i, segs[i])

    cf = conflicts(segs)
    same = [c for c in cf if c[4]]
    print(f"\ntotal conflicts: {len(cf)}  |  SAME-TIER (visible overlaps): {len(same)}  |  diff-tier: {len(cf) - len(same)}")
    from collections import Counter
    print("same-tier by kind:", dict(Counter(c[2] for c in same)))
    print("\nsame-tier conflicts (i, j, kind, point):")
    for i, j, kind, pt, _ in same:
        a, b = segs[i], segs[j]
        print(f"  [{i:3d}] t{a['tier']} {a['label'][:44]:44s} X [{j:3d}] t{b['tier']} {b['label'][:44]:44s} {kind} @ {pt}")


if __name__ == "__main__":
    main()

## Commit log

2026-08-19 make pcb more readable
    [haptic-console-control-unit.kicad_pcb]
2026-08-19 schematic: spread S1-S6 stack, clear title block, hide redundant pin numbers, flip net labels away from bodies
    [haptic-console-control-unit.kicad_sch]
2026-08-19 save cleaned-up schematic render (v2)
2026-08-19 make schematic more readable
    [haptic-console-control-unit.kicad_sch]
2026-08-19 S1-S6: swap 8-pin JST-XH-8 to 6-pin JST-XH-6, drop RST, match 6P standard pinout
    [haptic-console-control-unit.kicad_sch]
2026-08-19 Fix ERC power_pin_not_driven: retype Teensy 3V3/GND outputs to power_out
    ERC flagged #PWR1 (GND at B1) and #PWR33 (+3V3 at S1) as undriven power
    inputs. Netlist showed B1 itself is wired correctly (B1.1->GND, B1.2->/D20);
    the issue was the Teensy symbol declaring its 3.3V regulator output (pin 46)
    and GND output (pin 47) as plain 'output' instead of 'power_out'. KiCad ERC
    requires a power_out pin on a net to consider power inputs driven. Only the
    5V pin (55) was correctly typed, hence +5V net never errored.
    ERC after fix: 0 errors, 42 warnings (library path config only).
    [haptic-console-control-unit.kicad_sch]
2026-08-19 fix erc
    [haptic-console-control-unit.kicad_sch, temp-freerouting.dsn]
2026-08-19 more readable
    [haptic-console-control-unit.kicad_sch]
2026-08-20 fix perfboard
    [haptic-console-control-unit-perfboard.kicad_pcb]
2026-08-20 Fix wiring guide after Teensy header/R12-R13 perfboard re-layout
    Header sockets moved 1 col left / 2 rows up (row 25->23, 31->29) and
    R12/R13 shifted 2 columns since the guide was last generated. Every
    grid ref in the header tables, rail list, and connector destination
    columns was re-derived from the current .kicad_pcb placement and
    cross-checked against it programmatically. Also flags the new B23
    label collision (NP1 pin 8 vs Header A pin 1 - same letter+row,
    different physical holes, since the 32-col sequence reuses letters).
2026-08-20 Link README to the live GitHub Pages wiring guide
2026-08-20 Fix schemdraw diagram script output path and pin its venv deps
    control_unit_circuit.py hardcoded an output path outside this repo (leftover
    from wherever it was first drafted); it now resolves docs/ from __file__ and
    writes both the SVG and its PNG twin (via cairosvg) itself. Added
    scripts/requirements.txt for the dedicated scripts/.venv. The reusable
    schemdraw-drawing skill itself now lives at
    https://github.com/speedypleath/schemdraw-skill.
    [control_unit_circuit.py]
2026-08-20 Fix white background and layout overlaps in the schemdraw circuit diagram
    - bgcolor='white' on the drawing (was transparent, invisible on dark viewers)
    - pullup resistors (R12/R13) previously used no explicit length, so their
    default zigzag length overshot straight through the header/LED PWM rows
    below them; now routed horizontal with explicit .length() plus a plain
    (non-zigzag) vertical jog up to the 3V3 rail
    - widened the left-side connector-block IOs so label text no longer runs
    into the pin circle
    - moved the S1-S6 header further right so its pin column clears the pullup
    network, and increased Teensy pin spacing for breathing room between
    SDA/SCL/3V3 rows
    - fixed a GND label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
    [control_unit_circuit.py]
2026-08-20 Add TP1-TP5 test points (SDA/SCL/GND/+3V3/+5V) to schematic and both boards
    Schematic: 5 TestPoint symbols wired near the R12/R13 pullup network.
    Manufactured board: 5 THT test pads routed around the existing autorouted
    copper. Perfboard: real male 2.54mm header pins (not flat pads) at the
    board's last column, with S1-S6 shifted one column left to clear them.
    Wiring guide and README updated to match; full session notes in CLAUDE.md.
    [haptic-console-control-unit-perfboard.kicad_pcb, haptic-console-control-unit.kicad_pcb, haptic-console-control-unit.kicad_sch]
2026-08-21 update wiring guide
    [haptic-console-control-unit-perfboard.kicad_pcb]
2026-08-21 update wiring diagram
2026-08-21 Eliminate collinear wire overlaps in perfboard jumper wiring
    The back-side jumper wires are decorative footprints (no pads, no nets,
    invisible to DRC), so their only quality bar is legibility -- and 55 pairs
    were merging into each other. The prior session's z-tier stagger fixed
    mid-span crossings but not collinear overlaps: two wires sharing a row or
    column with overlapping spans, which no height offset can hide.
    Rewrote the generator around a span registry -- (net, lo, hi, tier) per grid
    line, checked at emit time, rejecting any leg that would overlap another net
    at the same tier. That makes "no overlaps" true by construction rather than
    by inspection. Tiers now come from greedy-colouring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
    [haptic-console-control-unit-perfboard.kicad_pcb]
2026-08-21 Regenerate wiring-guide diagram from the real 268-segment routing
    The inline back-side SVG was still drawn from the old 163-segment routing
    that the collinear-overlap rewrite (e446e23) replaced, so the diagram no
    longer matched the board. The original generator was session scratch and
    had not survived, so add scripts/gen_wiring_svg.py: it reads the same
    scripts/segments_v3.json that place_wire.py applies to the board, plus real
    pad positions from board_model.json, and rewrites the SVG in place.
    Diagram: 131 -> 268 wire lines, 157 pad dots, 34 ref labels, all 50 nets.
    Segments are emitted in z_tier order, so an over/under on the page is the
    over/under the physical wires have.
    Two legibility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
    [gen_wiring_svg.py]
2026-08-22 Add panel-side wiring guide and track wire model library
    docs/panel-wiring-guide.html is the companion to the board-side guide: it
    covers the panel end of every loom (action buttons, LED control buttons,
    joystick microswitches, numpad matrix) — crimp order, wire colours, and
    which connector pin each device lead lands on. Verified against the
    schematic netlist.
    Also start tracking the decorative jumper-wire 3D models used by the
    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
2026-08-22 Move LED resistors R1-R5 from hole row 49 to row 48
    The board was built with the resistors one row up from where the layout
    put them, so move the layout to match the hardware instead of reworking
    the board.
    R1 Z48/V48, R2 U48/Q48, R3 P48/L48, R4 K48/G48, R5 F48/B48. Only the five
    resistors and the ten wires that tap them moved; every other footprint,
    wire ref and net is untouched, so nothing already soldered is invalidated.
    Background hole-grid vias were removed under the new pad positions and
    added back at the vacated ones (via/pad totals net out unchanged).
    Verified: verify_v3 clean (268 segments, 50 nets, 0 taps off-wire, 0
    disconnected, 0 out-of-bounds), 0 same-tier wire overlaps, 104/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
    [haptic-console-control-unit-perfboard.kicad_pcb]
2026-08-24 Remap every GPIO to its nearest Teensy pin, fix stale CB4/D13 doc note
    Every connector signal (B1-B8, CB1-5, J1/J2, NP1, LED1-5) now sits on
    whichever Teensy pin is physically closest to it on the board instead
    of a contiguous functional block, solved as a bipartite matching over
    Manhattan wire distance. Schematic labels, the manufactured board's
    nets/routing, and the perfboard's hand-wiring layout were all
    regenerated from the new scripts/pin_map.json; docs and renders follow.
    Also drops the panel wiring guide's leftover "CB4 sits on pin 13"
    hazard callout, which the remap made false (D13 moved to NP1's row-0
    output) - the equivalent warning already lives in the NP1 section.
    Co-Authored-B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
    [haptic-console-control-unit-perfboard.kicad_pcb, haptic-console-control-unit.kicad_pcb, haptic-console-control-unit.kicad_sch]
2026-08-24 Fix ROW_A tie-break bug in GPIO pin-map generator, resync docs
    gen_pin_map.py's per-connector tie-break scored pin order by raw GPIO
    number, which is backwards for Teensy header row A (its physical hole
    order runs opposite its GPIO numbering) -- it silently preferred a
    layout where J1's wires crossed even though swapping them was free.
    Fixed to score by real header-pin position instead.
    Regenerating pin_map.json from the fixed script also caught that the
    previously-committed file predated the generator's bottleneck-
    minimizing pass and had drifted (worst-case wire 86.4mm instead of the
    achievable 58.5mm, same 1630.8mm total). Between the two fixes, 26 of
    40 signals moved pins -- see the new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
    [gen_pin_map.py]
2026-08-26 Resync every KiCad artifact to the current pin map (LED4 frozen on D13)
    R4's LED jumper was re-landed from R29 (D16 = J1 pin 4, already soldered) to
    O29 (D13), clearing the hardware conflict flagged last session. LED4 joins the
    frozen set, which now holds 18 already-soldered conductors: B1-B8, J1/J2, LED4,
    LED5. Freezing it costs nothing -- the solver had already chosen D13 -- so the
    map stays at 1356.3 mm total Manhattan run, 61.0 mm longest wire.
    - Schematic: 44 net labels renamed to their GPIO names (D<n>) via delete +
    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
    [haptic-console-control-unit-perfboard.kicad_pcb, haptic-console-control-unit.kicad_pcb, haptic-console-control-unit.kicad_sch]
2026-08-26 Correct CLAUDE.md: the jumper-wires-kicad fixes were never outstanding
    Six session notes in a row claimed the back-layer / m_Scale / m_Offset fixes
    were sitting uncommitted in ~/KiCad/jumper-wires-kicad. They were committed
    and pushed as 8aa55cd on 2026-08-21; the claim was copied forward from note to
    note without re-checking git status in that repo. Also records where this
    session's two commits landed.
